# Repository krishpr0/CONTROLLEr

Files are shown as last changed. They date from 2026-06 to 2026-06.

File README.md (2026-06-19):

# CONTROLLER

CONTROLLER, IT is an Circuit which allows any type of SSD/HDD of a laptop size which is 2.5 inch Memory be a External Storage. This Project main chip is the ASM2464PD due to its high speed transfer speed. This chip was selected due to its support of USB4/Thunderbolt.

ZINE

## What is this Project?
Controller is a high speed transfer external circuit board which is meant to make any 2.5 inch hard drive or ssd into an external Storage system. This unlocks the ability to make our own external storage system rather then buying it from outside. 

## How do we use Controller?
- First of all there are 4 screws on the side 2 on each unscrew it!
- Then pull of the top cover off the base plate.
- Then insert and slide in the HDD/SSD onto the PCIe connector.
- Place the cover plate back on and then tighten the screw 2 on each side this should secure the storage as well as the top case.
- Then connect to the computer that's it!
- (*NOTE: SOME MAY REQUIRE TO FLASH A FIRMWARE*)

## The reason for building this
Nowadays the software programs are increasing in size and as the phoots, videos we click also getting bigger and bigger. In my case each of my photos clicked is more than 5MB so that storage would rlly quickly fill up and I had to either delete it or buy an external drive and store it there.!

And so I choose the 2nd opt buy and external drive to store it cuz why delete photos which is memoory.!
So yeh like that it went on for years and years pile of drives js filled with photos, videos and files but now the storage are getting more expensier and also the casing used to hold the drive. !

SO i was really frustraied atp And i thought abt is there a way to make a good external drive !?
SO that was the reason i started this project due to the rise in price of storage due to AI>
T-T

## CAD
CASE
!@45
!)(@

## CIRCUIT DIAGRAM: 










## PCB


## PCB 3D


# BOM
| #  | Reference | Value | Footprint | Qty | Unit (USD) | Total (USD) | Datasheet / Link |
|----|---|---|---|-----|---|---|---|
| 1  | U1 | ASM2464PD  USB4 Host Controller | ASM2464PD | 1 | $8.000 | $8.000 | https://www.asmedia.com.tw/product/aGaq3YfSP5Yrq0T0/cGaq7XeSw9YRQ5T1 |
| 2  | U2 | SPI Flash  SOIC-8  (Firmware storage) | SOIC-8_5.3x5.3mm_P1.27mm | 1 | $3 | $3 | http://ww1.microchip.com/downloads/en/DeviceDoc/21832H.pdf |
| 3  | U3 | SPI Flash  DFN-8  (Firmware storage) | DFN-8-1EP_3x2mm_P0.5mm | 1 | $3 | $3 | http://ww1.microchip.com/downloads/en/DeviceDoc/21832H.pdf |
| 4  | Y1 | 25MHz Crystal  SMD 3225-4Pin | Crystal_SMD_3225-4Pin_3.2x2.5mm | 1 | $0.350 | $0.350 | https://au.rs-online.com/web/p/crystal-units/9047531 |
| 5  | J1 | USB-C Receptacle  Amphenol 12401610E4-2A | USB_C_Receptacle_Amphenol | 1 | $1.200 | $1.200 | https://www.usb.org/sites/default/files/documents/usb_type-c.zip |
| 6  | J2 | SPI Header  2x04  2.54mm | PinHeader_2x04 | 1 | $0.100 | $0.100 | --- |
| 7  | J3 | PCIe x4 Connector  THT Open | PCIe_x4_tht_open | 1 | $1.500 | $1.500 | http://www.ritrontek.com/uploadfile/2016/1026/20161026105231124.pdf |
| 8  | J4 | Chip Annoyers Header  2x02  2.54mm | PinHeader_2x02 | 2 | $0.10 | $0.10 | https://www.digikey.com/en/products/detail/harwin-inc/M20-9990246/3728226 |
| 9  | J5 | UART Header  1x04  2.54mm | PinHeader_1x04 | 1 | $0.10 | $0.050 | https://www.digikey.com/en/products/detail/jst-sales-america-inc/B4B-XH-A/1651047 |
| 10 | J6 | I2C Header  1x04  2.54mm | PinHeader_1x04 | 1 | $0.10 | $0.050 | https://www.digikey.com/en/products/detail/jst-sales-america-inc/B4B-XH-A/1651047 |
| 11 | J7,J8,J9,J10 | 1x06 Header  1.27mm  x4 | PinHeader_1x06 | 4 | $0.20 | $0.200 | https://www.digikey.in/en/products/detail/jst-sales-america-inc/B6B-PH-K-S/926615 |
| 12 | R1,R2,R20,R24,R26,R29,R39,R41,R42,R43 | 1k ohm  0402 | R_0402_1005Metric | 10  | $0.15 | $1.50 | https://www.digikey.com.au/en/products/detail/yageo/RC0402FR-071KL/726513 |
| 13 | R3,R4,R5,R6,R7,R8,R25,R30,R31 | 0 ohm  0402 | R_0402_1005Metric | 9 | $0.15 | $1.35 | https://www.digikey.com.au/en/products/detail/yageo/RC0402JR-070RL/726406 |
| 14 | R9,R27,R28,R35,R38,R34,R36,R37 | 4.7k ohm  0402 | R_0402_1005Metric | 8 | $0.15 | $0.75 | https://www.digikey.com.au/en/products/detail/yageo/RC0402JR-074K7L/726477 |
| 15 | R10,R21,R22, R23 | 10k ohm  0402 | R_0201_0603Metric | 4 | $0.15 | $0.60 | https://www.digikey.com.au/en/products/detail/vishay-dale/CRCW040210K0FKED/1178121 |
| 16 | R11,R12,R13,R14,R15,R16,R17,R18 | 220k ohm  0201 | R_0201_0603Metric | 8 | $0.15 | $1.20 | https://www.digikey.com/en/products/detail/yageo/RC0201JR-07220KP/15219948 |
| 19 | R32 | 12.1k ohm  0402 | R_0402_1005Metric | 1 | $0.10 | $0.10 | https://www.digikey.in/en/products/detail/yageo/RC0402FR-1012K1L/17020868 |
| 20 | R33 | 100k ohm  0402 | R_0402_1005Metric | 1 | $0.20 | $0.20 | https://www.digikey.com/en/products/detail/yageo/AT0402BRD07100KL/5138605 |
| 22 | C1 | 10pF  0402 | C_0402_1005Metric | 1 | $0.10 | $0.10 | https://www.digikey.com/en/products/detail/yageo/CC0402JRNPO8BN100/5883266 |
| 23 | C2,C3,C4,C5,C6,C7,C8,C9 | 330nF  0201 | C_0201_0603Metric | 8 | $0.10 | $0.80 | https://www.mouser.in/ProductDetail/Walsin/0201X334M6R3CT?qs=iLbezkQI%252Bsj6TtN1Mk8apQ%3D%3D |
| 24 | C10,C21 | 1uF  0402 | C_0402_1005Metric | 2 | $0.01 | $0.02 | https://robu.in/product/1uf-capacitor-smdc-0402-pack-of-50/ |
| 25 | C11 | 220pF  0402  DNP | C_0402_1005Metric | 1 | $0.10 | $0.10 | https://www.digikey.com/en/products/detail/yageo/CC0402GRNPO9BN221/5883253 |
| 26 | C12,C13,C14,C15,C16,C17,C18,C19 | 220nF  0402 | C_0402_1005Metric | 8 | $0.003 | $0.024 | https://www.lcsc.com/product-detail/C2649521.html |
| 27 | C20 | 100nF  0402 | C_0402_1005Metric | 1 | $0.003 | $0.003 | https://www.lcsc.com/product-detail/C60474.html |
| 28 | D1,D2,D3,D4,D5,D6,D7,D8 | Diode  0201  DNP | D_0201_0603Metric | 8 | $0.32 | $2.56 | https://www.digikey.in/en/products/detail/kyocera-avx/GG020105100N2P/6826542 |
| 29 | D9,D10,D11,D12,D13,D14,D15,D16 | LED  0603 | LED_0603_1608Metric | 8 | $0.01 | $0.08 | https://www.lcsc.com/product-detail/C19171390.html |
| | TOTAL | | | | | 15.462 | |

# HOW TO BUILD










## What you need
-  Soldering Iron
-  Soldering wire
-  Flux
-  Multimeter
-  USB-C Cable

### Assembly Order
1. Solder all SMD Passives first (Resistors, Capacitors)
2. Solder ICs
3. Solder USB-C
4. Connect the PCIe Connecotr
5. Connect the Drive
6. Plug and Transfer.

### Firmware Setup 
- Open the 'firmware/src' - Upload the whole program to the SPI
- RUN

# Feature
- 1MB ROM
- SPI
- 40 GBPS USB Transfer Speed
- USB4/Thuerbolt Support
- HHD/SSD/NVMe support
- USB-C
- Power effiecent

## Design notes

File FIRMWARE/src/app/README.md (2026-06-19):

# ASM2464PD Application Tools

Tools for interacting with the ASM2464PD USB-to-PCIe bridge chip.

## probe_dma.py

Tests GPU DMA access to the ASM2464's internal SRAM buffer.

### Usage

```bash
# Basic DMA test - write via USB, read via GPU SDMA
sudo PYTHONPATH=~/tinygrad AMD_IFACE=USB python app/probe_dma.py

# Probe accessible region size
sudo PYTHONPATH=~/tinygrad AMD_IFACE=USB python app/probe_dma.py --probe-size
```

### What it tests

1. Writes test pattern to ASM2464 SRAM via USB (scsi_write to 0xF000)
2. Boots AMD GPU via tinygrad with USB interface
3. Uses GPU SDMA to copy data from PCIe address 0x200000 to GPU VRAM
4. Verifies the GPU read the correct data

This validates the DMA path: `USB -> ASM2464 SRAM <- GPU SDMA (PCIe 0x200000)`

## scan_pcie.py

Scans for PCIe devices connected via the ASM2464PD USB enclosure.

### Usage

```bash
# Quick scan (finds bridges but not downstream GPU functions)
sudo PYTHONPATH=~/tinygrad python app/scan_pcie.py

# Deep scan - configures all bridges to find GPU at bus 4
sudo PYTHONPATH=~/tinygrad python app/scan_pcie.py --deep

# Verbose mode with config space dumps
sudo PYTHONPATH=~/tinygrad python app/scan_pcie.py --deep --verbose

# Scan specific bus
sudo PYTHONPATH=~/tinygrad python app/scan_pcie.py --bus 4
```

### Example Output (with AMD RX 7900 XTX)

```
Bus 00: 32x ASM2461 PCIe Switch Ports
Bus 01: 1x ASM2461 downstream port  
Bus 02: AMD Navi 31 Upstream Port [1002:1478]
Bus 03: AMD Navi 31 Downstream Port [1002:1479]
Bus 04:
  04:00.0: AMD Navi 31 (RX 7900 XTX) [1002:744C] - Display Controller
  04:00.1: AMD Navi 31 HDMI Audio [1002:AB30] - Multimedia Controller
```

## Memory Architecture

The ASM2464PD has several memory regions accessible via different paths:

### 1. GPU-Accessible PCIe Regions (DMA Buffer)

These regions are accessible by the GPU via PCIe DMA (SDMA engine). The GPU's page
tables map virtual addresses to these PCIe physical addresses with `AddrSpace.SYS`.

| PCIe Address Range | Size | Purpose |
|---|---|---|
| 0x200000 - 0x27FFFF | 512 KB | Copy buffer (USB bulk DMA) |
| 0x800000 - 0x800FFF | 4 KB | Queue page 0 |
| 0x808000 - 0x808FFF | 4 KB | Queue page 1 |
| 0x820000 - 0x820FFF | 4 KB | Sys buffer (tinygrad) |
| 0x828000 - 0x828FFF | 4 KB | Queue page 3 |

**Total GPU-accessible**: 528 KB (512 KB contiguous + 4x4 KB pages)

The GPU can read/write these regions via SDMA. tinygrad maps them as:
- `copy_bufs[0]`: 512KB at PCIe 0x200000 (ctrl_addr 0xF000)
- `sys_buf`: 4KB at PCIe 0x820000 (ctrl_addr 0xA000)

### 2. USB-Accessible XDATA Windows

The 8051 firmware exposes these regions to USB via E4/E5 vendor commands:
- `0x8000-0x8FFF`: 4KB window (USB descriptor buffer)
- `0xF000-0xFFFF`: 4KB window (maps to PCIe 0x200000, first 4KB only)

**Note**: USB E4/E5 commands can only access the first ~4KB of the copy buffer.
The full 512KB is only accessible via GPU SDMA or SCSI bulk write.

### 3. XDATA (E4/E5 Vendor Commands)

Firmware XDATA memory accessible via USB vendor commands:
- **E4**: Read from XDATA address (up to 255 bytes)
- **E5**: Write to XDATA address (1 byte at a time)

```python
from tinygrad.runtime.support.usb import ASM24Controller
usb = ASM24Controller()

# Read 16 bytes from XDATA 0x8000
data = usb.read(0x8000, 16)

# Write bytes to XDATA 0xF000
usb.write(0xF000, b'\xDE\xAD\xBE\xEF')
```

### 4. SCSI Bulk DMA Path (Fast)

High-speed path for bulk data transfers to internal SRAM:

```python
# Write up to 64KB at a time via SCSI bulk transfer
usb.scsi_write(data, lba=0)  # Data lands at 0xF000 window
```

This is the fast path used by tinygrad for GPU memory transfers:
- USB3 bulk packets (1024 bytes each)
- Hardware DMA to internal SRAM
- No CPU involvement for data bytes

### 5. PCIe Memory (TLP Requests)

Direct PCIe memory read/write via TLP (Transaction Layer Packets):

```python
# Read 4 bytes from PCIe memory address
val = usb.pcie_mem_req(address, value=None, size=4)

# Write 4 bytes to PCIe memory address  
usb.pcie_mem_req(address, value=0xDEADBEEF, size=4)

# Batch writes for better performance
usb.pcie_mem_write(address, [val1, val2, val3, ...], size=4)
```

**Note**: PCIe memory requests go to EXTERNAL devices (GPU, NVMe), not internal SRAM.

## DMA Transfer Flow

### USB Host to GPU Memory

```
1. Host sends data via USB bulk transfer
2. ASM2464 firmware DMAs to internal SRAM (0x00200000+)
3. Data visible at XDATA 0xF000 window
4. Firmware can issue PCIe TLP to copy SRAM to GPU BAR

Or using tinygrad's copy_bufs mechanism:
1. scsi_write() to 0xF000 (lands in SRAM at ctrl_addr)
2. GPU reads from mapped sys_addr via PCIe
```

### GPU Memory to USB Host

```
1. GPU writes to mapped memory region
2. Firmware reads via PCIe TLP or DMA
3. Data copied to SRAM
4. USB bulk IN transfer to host
```

## Key Registers

### PCIe TLP Engine (0xB2xx)

| Register | Purpose |
|---|---|
| 0xB210 | TLP format/type (0x20=mem read, 0x60=mem write) |
| 0xB217 | Byte enables |
| 0xB218 | Address bits 0-7 |
| 0xB219 | Address bits 8-15 |
| 0xB21A | Address bits 16-23 |
| 0xB21B | Address bits 24-31 |
| 0xB21C | Address bits 32-39 (high) |
| 0xB220 | Data (read result / write value) |
| 0xB254 | Trigger (write 0x0F) |
| 0xB296 | Status (bit 1 = complete, bit 0 = error) |

### SCSI DMA Engine (0xCExx)

| Register | Purpose |
|---|---|
| 0xCE00 | DMA control (write 0x03 to start) |
| 0xCE75 | Transfer length |
| 0xCE76 | PCI address byte 0 (LSB) |
| 0xCE77 | PCI address byte 1 |
| 0xCE78 | PCI address byte 2 |
| 0xCE79 | PCI address byte 3 (MSB) |
| 0xCE89 | State machine (bit 0=ready, bit 1=success) |

## Requirements

- Python 3.10+
- tinygrad (for `ASM24Controller`)
- libusb
- Root access for USB device

```bash
# Install tinygrad
git clone https://github.com/tinygrad/tinygrad ~/tinygrad

# Run with correct path
sudo PYTHONPATH=~/tinygrad python app/scan_pcie.py
```

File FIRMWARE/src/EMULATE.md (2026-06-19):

Our goal is to get the emulation of the firmware running as an emulated USB device on the computer

- Emulator should run in its own thread. It should use the original firmware in fw.bin
- All communication with the emulator should be through MMIO
- It registers a dummy hcd SuperSpeed device, much be superspeed
- patch.py should work and have a model emulating the flash
- All descriptors are handled by logic in the firmware, NEVER HARDCODE ANY PIECE OF DESCRIPTORS
- All functions are handled by logic in the firmware
- The firmware runs in it's own thread and polling is done through MMIO
- There should be nothing parsing the commands in Python, the Python should just be a bridge
- The device should enumerate and show up in lsusb
- The device should show up as a mass storage device

## Current Status

### Working:
- Device enumeration (shows up in lsusb as 174c:2461)
- USB device descriptor handling via firmware DMA
- USB config descriptor with correct wTotalLength (121 bytes, includes both alt_settings)
- String descriptor handling
- Control transfers (GET_DESCRIPTOR, GET_MAX_LUN, BULK_ONLY_RESET)
- USB 2.0 High Speed mode (dummy_hcd only supports up to USB 2.0)

### Not Working:
- Bulk transfers (CBW/CSW for mass storage)
  - The bulk endpoint (0x02 OUT, 0x81 IN) is enabled but ep_read blocks
  - This may be a dummy_hcd limitation or a raw-gadget configuration issue
- UAS mode (requires USB 3.0 bulk streams, not supported by dummy_hcd)

### Known Limitations:
1. **dummy_hcd only supports USB 2.0 High Speed**
   - USB 3.0 SuperSpeed is not available
   - UAS mode requires USB 3.0 streams which are not supported
   - Device enumerates at High Speed, so USB 2.0 device descriptor is used

2. **Bulk transfers not functional**
   - The raw-gadget ep_read call blocks indefinitely waiting for data
   - Host-side libusb bulk transfers timeout with error -7
   - Control transfers work correctly, only bulk transfers are affected

## Running the Emulator

```bash
cd emulate
sudo modprobe dummy_hcd num=1
sudo modprobe raw_gadget
sudo python3 usb_device.py
```

The device will appear in lsusb:
```
Bus 005 Device XXX: ID 174c:2461 ASMedia Technology Inc. AS2462
```

## Testing

The test program `test_patch_usb.py` validates:
1. Device enumeration - PASS
2. Mass storage (BBB protocol) - FAIL (bulk transfers)
3. Vendor commands (E4/E5) - FAIL (requires bulk transfers)
4. String descriptors - PASS

Run with:
```bash
echo -n "5-1:1.0" | sudo tee /sys/bus/usb/drivers/usb-storage/unbind
sudo PYTHONPATH=/home/tiny/tinygrad python3 test_patch_usb.py
```

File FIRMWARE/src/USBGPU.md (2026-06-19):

# ASM2464PD as USBGPU - How Tinygrad Uses It

## Overview

Tinygrad uses the ASM2464PD USB4-to-NVMe bridge as a "USB GPU" by exploiting its PCIe
initiator capability and large internal SRAM buffer. This document explains the actual
implementation and identifies the slow path that needs improvement.

## Hardware Architecture

```
USB Host (tinygrad)           ASM2464PD Bridge                   GPU
       │                            │                              │
       │  USB3 Bulk Streams         │  PCIe TLPs                   │
       │  (31 concurrent)           │                              │
       │                            │                              │
       ├──EP 0x02 OUT (data)───────>│                              │
       ├──EP 0x04 OUT (commands)───>│  8051 CPU                    │
       │                            │     │                        │
       │<──EP 0x81 IN (data)────────│     ├──Config Space──────────>│
       │<──EP 0x83 IN (status)──────│     ├──Memory Write──────────>│
       │                            │     └──Memory Read───────────>│
       │                            │            │                  │
       │                            │            v                  │
       │                      Internal SRAM (6-8 MB)               │
       │                      ┌────────────────────┐               │
       │                      │ Data @ 0x00200000  │<──GPU DMA────>│
       │                      │ Queues @ 0x00820000│               │
       │                      └────────────────────┘               │
```

## Tinygrad's USB Communication

### Endpoints Used

| Endpoint | Direction | Purpose |
|---|---|---|
| 0x02 | OUT | Bulk data to device (SCSI writes) |
| 0x04 | OUT | SCSI command blocks |
| 0x81 | IN | Bulk data from device |
| 0x83 | IN | SCSI status responses |

### Buffer Allocations (from usb.py)

```python
# Per-stream buffers (31 streams for USB3 bulk streaming)
buf_data_out = 512 KB per stream    # Host → Device data
buf_data_in  = 4 KB per stream      # Device → Host data (NOTE: small!)
buf_cmd      = 32 bytes             # SCSI CDB wrapper
buf_stat     = 64 bytes             # Status response
```

### Transfer Methods

**1. SCSI WRITE (Fast - 64KB chunks)**
```python
# ScsiWriteOp in usb.py line 147-149
struct.pack('>BBQIBB', 0x8A, 0, op.lba, sectors, 0, 0)
# 0x8A = SCSI WRITE(16) opcode
# lba = Logical Block Address (maps to PCI address 0x00200000 + lba*512)
# sectors = size / 512

# Chunking (usb.py lines 156-160)
for i in range(0, len(buf), 0x10000):  # 64 KB chunks
    self.exec_ops([ScsiWriteOp(buf[i:i+0x10000], lba), ...])
```

**2. E4 Read (SLOW - 255 byte chunks)**
```python
# ReadOp in usb.py line 143-146
struct.pack('>BBBHB', 0xE4, op.size, addr >> 16, addr & 0xFFFF, 0)
# op.size limited to 0xFF (255 bytes)

# Read method (usb.py line 165-167)
def read(self, base_addr, length, stride=0xff):  # stride = 255!
    parts = self.exec_ops([ReadOp(base_addr + off, min(stride, length - off))
                           for off in range(0, length, stride)])
```

**3. E5 Write (Register access - 1 byte at a time)**
```python
# WriteOp in usb.py line 136-141
struct.pack('>BBBHB', 0xE5, value, addr >> 16, addr & 0xFFFF, 0)
# Single byte per command - used for MMIO register writes, not bulk data
```

### Speed Comparison

| Operation | Chunk Size | Throughput | Use Case |
|---|---|---|---|
| SCSI WRITE (0x8A) | 64 KB | ~100+ MB/s | Fast bulk OUT |
| E4 Read (0xE4) | 255 bytes | ~1-5 MB/s | **SLOW** bulk IN |
| E5 Write (0xE5) | 1 byte | ~10-50 KB/s | Register config |
| PCIe MemWr | 4 bytes | ~4 MB/s | GPU BAR writes |
| PCIe MemRd | 4 bytes | ~2 MB/s | GPU BAR reads |

**The asymmetry is severe**: Writes are ~20-100x faster than reads.

## The Firmware Patch

Tinygrad's `patch.py` downloads ASMedia firmware and makes one modification:

```python
patches = [(0x2a0d + 1 + 4, b'\x0a', b'\x05')]
# File offset: 0x2a12
# Changes: mov r7, #0x0a → mov r7, #0x05
```

### What The Patch Does

At code address 0x2a0d, there's a SCSI write completion status check:

```c
// From src/app/protocol.c lines 2250-2267
if (*ptr != 0) {
    goto return_0x0a;  // Return error code 10
}
// ...
return_0x0a:
    // NOTE: patch.py changes this return value from 0x0a to 0x05
    return 0x0a;  // Original returns 10
```

The patch changes this return value from 0x0a (10) to 0x05 (5).

**Why?** The return value is a status code that affects the SCSI state machine.
Code 10 (0x0a) indicates one type of completion status, while code 5 (0x05)
indicates another. The patch likely changes how partial/retry scenarios are
handled to make the write path more reliable for tinygrad's usage pattern.

### VID/PID Change

The patch also changes the device identity via config blocks:

```
Original:  VID=0x174C PID=0x2464 (ASMedia USB4 NVMe)
Patched:   VID=0xADD1 PID=0x0001 ("tiny")
```

This allows tinygrad to identify its patched devices.

## Internal SRAM Buffer

### Size: 6-8 MB

```
PCI Address       Purpose
0x00200000        Data buffer start (6+ MB available)
0x00820000        NVMe queues (can be repurposed)

Gap = 0x00620000 = 6.125 MB for data buffer
```

### LBA Addressing

SCSI commands use LBA (Logical Block Address) which firmware converts:

```
buffer_addr = 0x00200000 + (LBA × 512)
```

So `ScsiWriteOp(data, lba=256)` writes to PCI address:
```
0x00200000 + (256 × 512) = 0x00220000
```

### 32-bit DMA Addressing

The 8051 has 64KB address space but accesses the full buffer via DMA registers:

```
Register   Purpose
CE76-CE79  32-bit DMA address (little-endian)
```

USB bulk transfers program these registers and let hardware DMA handle the data.
The 8051 CPU never touches the bulk data bytes.

## The Slow Path Problem

### Why E4 Reads Are Slow

E4 is a vendor-specific SCSI command for register/memory reads:

1. **Limited to 255 bytes per request** (line 143: `assert op.size <= 0xff`)
2. **Control transfer overhead** - each E4 goes through SCSI CDB processing
3. **No bulk streaming** - cannot pipeline like SCSI WRITE does

### Why SCSI READ Isn't Used

Standard SCSI READ(16) command (opcode 0x88) isn't implemented in tinygrad.
The firmware supports it, but tinygrad only implemented SCSI WRITE.

### Comparison: SCSI WRITE vs E4 READ

```
SCSI WRITE (current - fast):
  1 command → 64KB data → 1 status
  ~100 MB/s

E4 READ (current - slow):
  1 command → 255 bytes data → 1 status
  × 4000 times for 1 MB
  ~1-5 MB/s
```

## Plan to Fix the Slow Path

### Option 1: Implement ScsiReadOp (Recommended)

Add SCSI READ(16) support to tinygrad, mirroring the write path:

```python
@dataclasses.dataclass(frozen=True)
class ScsiReadOp: size:int; lba:int=0

# In exec_ops:
elif isinstance(op, ScsiReadOp):
    sectors = round_up(op.size, 512) // 512
    _add_req(struct.pack('>BBQIBB', 0x88, 0, op.lba, sectors, 0, 0),
             sectors * 512, None)  # Request data IN

def scsi_read(self, size:int, lba:int=0) -> bytes:
    # Chunk reads like writes
    result = b''
    for i in range(0, size, 0x10000):
        chunk_size = min(0x10000, size - i)
        resp = self.exec_ops([ScsiReadOp(chunk_size, lba + i // 512)])
        result += resp[0][:chunk_size]
    return result
```

**Expected improvement:** 255 bytes → 64 KB per request = **~250x faster**

### Option 2: Batch E4 Requests

If firmware changes are easier than tinygrad changes:

```python
# Current: Sequential 255-byte reads
for off in range(0, length, 255):
    result += exec_ops([ReadOp(addr + off, 255)])

# Better: Parallel 255-byte reads (use all 31 streams)
reads = [ReadOp(addr + off, 255) for off in range(0, length, 255)]
results = exec_ops(reads[:31])  # 31 concurrent = 7.9KB per batch
```

**Expected improvement:** ~31x faster (still limited by E4 overhead)

### Option 3: Larger E4 Transfers (Firmware Change)

The 255-byte limit is arbitrary. Firmware could support larger E4 reads:

```c
// Current: uint8_t limits to 255
// Change: Use 16-bit length field in E4 command

// E4 format: 0xE4 [size_hi] [addr>>16] [addr_lo] [addr_hi] [size_lo]
// Allows up to 64KB per E4 request
```

**Expected improvement:** ~250x faster with firmware mod

### Option 4: Use GPU Bus Mastering

For large reads from GPU memory, use the GPU as bus master:

1. GPU DMAs data to PCI address 0x00200000 (bridge's SRAM)
2. Tinygrad reads from SRAM via SCSI READ or E4
3. Eliminates slow PCIe MemRd TLPs from 8051

**Expected improvement:** GPU-limited rather than bridge-limited

## Summary

| Path | Current | After Fix | Improvement |
|---|---|---|---|
| USB → Device (SCSI WRITE) | 64 KB/cmd | 64 KB/cmd | Already fast |
| Device → USB (E4 READ) | 255 B/cmd | 64 KB/cmd | **~250x** |
| 8051 → GPU (PCIe MemWr) | 4 B/TLP | 4 B/TLP | Can't improve* |
| GPU → 8051 (PCIe MemRd) | 4 B/TLP | 4 B/TLP | Can't improve* |
| GPU ↔ SRAM (bus master) | N/A | ~4 GB/s | Use this! |

*The 8051-initiated PCIe path is fundamentally slow (~4 MB/s max). Use GPU
bus mastering for high-throughput data movement.

## Quick Reference

### Tinygrad Device Opening

```python
# From usb.py line 117
self.usb = USB3(0xADD1, 0x0001, 0x81, 0x83, 0x02, 0x04)
#              VID     PID     data_in stat_in data_out cmd_out
```

### Controller Initialization

```python
# usb.py lines 123-124
self.exec_ops([
    WriteOp(0x54b, b' '),        # Unknown config
    WriteOp(0x54e, b'\x04'),     # Unknown config
    WriteOp(0x5a8, b'\x02'),     # Unknown config
    WriteOp(0x5f8, b'\x04'),     # Unknown config
    WriteOp(0x7ec, b'\x01\x00\x00\x00'),  # 4-byte config
    WriteOp(0xc422, b'\x02'),    # Enable something
    WriteOp(0x0, b'\x33'),       # Start signal?
])
```

### PCIe Memory Access

```python
# usb.py lines 185-214
def pcie_request(self, fmt_type, address, value=None, size=4):
    # fmt_type: 0x60=MemWr, 0x20=MemRd
    # Writes to B210-B296 registers to generate TLPs

def pcie_mem_write(self, address, values, size):
    # Batch PCIe memory writes (4 on OSX, 16 on Linux per batch)
```

---

# Hardware Blocks for USBGPU Firmware

This section details all hardware blocks in the ASM2464PD and their relevance for
a USBGPU-specific firmware rewrite.

## Block Diagram

```
                              ASM2464PD SoC
    ┌──────────────────────────────────────────────────────────────────┐
    │                                                                  │
    │  ┌──────────┐    ┌──────────────────────────────────────────┐   │
    │  │  8051    │    │           Internal SRAM (6-8 MB)          │   │
    │  │   CPU    │    │  ┌────────────────────────────────────┐  │   │
    │  │ ~100MHz  │    │  │ 0x00200000: Data Buffer (6 MB)     │  │   │
    │  │          │    │  │ 0x00820000: Queue Region (128 KB)  │  │   │
    │  │ 64KB     │    │  └────────────────────────────────────┘  │   │
    │  │ XDATA    │    │                    ▲                     │   │
    │  │ views    │    │                    │ 32-bit DMA          │   │
    │  └────┬─────┘    └────────────────────┼─────────────────────┘   │
    │       │                               │                         │
    │       ▼                               ▼                         │
    │  ┌─────────────────────────────────────────────────────────┐   │
    │  │                    DMA Engines                          │   │
    │  │  ┌─────────┐  ┌─────────┐  ┌─────────┐  ┌─────────┐    │   │
    │  │  │USB DMA  │  │SCSI DMA │  │XFER DMA │  │Flash DMA│    │   │
    │  │  │0x90xx   │  │0xCExx   │  │0xCCxx   │  │0xC8Ax   │    │   │
    │  │  └────┬────┘  └────┬────┘  └────┬────┘  └────┬────┘    │   │
    │  └───────┼────────────┼────────────┼────────────┼──────────┘   │
    │          │            │            │            │               │
    │          ▼            ▼            ▼            ▼               │
    │  ┌─────────────┐ ┌─────────────┐ ┌──────┐ ┌──────────────┐     │
    │  │USB3 Ctrl   │ │PCIe Engine  │ │Timers│ │SPI Flash     │     │
    │  │0x9000-93FF │ │0xB200-B4FF  │ │0xCC10│ │0xC89F-C8AE   │     │
    │  │            │ │             │ │      │ │              │     │
    │  │EP0 Control │ │TLP Generate │ │Timer0│ │Config Store  │     │
    │  │EP1 Bulk IN │ │Config Space │ │Timer1│ │              │     │
    │  │EP2 Bulk OUT│ │Memory R/W   │ │Timer2│ │              │     │
    │  └──────┬─────┘ └──────┬──────┘ │Timer3│ └──────────────┘     │
    │         │              │        └──────┘                       │
    └─────────┼──────────────┼───────────────────────────────────────┘
              │              │
              ▼              ▼
         USB3 PHY       PCIe PHY
              │              │
              ▼              ▼
         To Host         To GPU
```

## Hardware Blocks - Detailed Analysis

### 1. USB3 Controller (0x9000-0x93FF) - **ESSENTIAL**

The USB3 controller handles all host communication. **Required for USBGPU.**

| Register Range | Purpose | USBGPU Need |
|---|---|---|
| 0x9000-0x901F | Core USB status/control | Required |
| 0x905A-0x90FF | Endpoint configuration | Required |
| 0x9091-0x9092 | Control transfer phase, DMA trigger | Required |
| 0x9100-0x912F | Link status, CDB registers | Required |
| 0x91C0-0x91FF | USB PHY control | Required |
| 0x9200-0x92FF | Power management | Required |
| 0x9E00-0x9E07 | Setup packet buffer | Required |

**Key Registers for USBGPU:**
```
0x9000  USB_STATUS      - Connection state (bit 7=connected)
0x9091  USB_CTRL_PHASE  - Control transfer state machine
0x9092  USB_DMA_TRIGGER - Triggers descriptor DMA
0x9100  USB_LINK_STATUS - USB speed (bits 0-1: 2=SuperSpeed)
0x910D-0x9112 USB_CDB   - SCSI Command Descriptor Block
0x9E00-0x9E07 Setup Pkt - 8-byte USB setup packet
```

**Simplification:** Remove Mass Storage class, use Vendor class for simpler protocol.

---

### 2. SCSI/Bulk DMA Engine (0xCE00-0xCE9F) - **ESSENTIAL**

This is the high-speed bulk transfer engine. **Critical for USBGPU performance.**

| Register Range | Purpose | USBGPU Need |
|---|---|---|
| 0xCE00-0xCE01 | DMA control/parameter | Required |
| 0xCE40-0xCE45 | DMA parameters | Required |
| 0xCE55 | Tag value | Required |
| 0xCE66-0xCE67 | Tag count, queue status | Required |
| 0xCE70-0xCE79 | Transfer control, **32-bit PCI address** | **Critical** |
| 0xCE86-0xCE89 | USB/DMA state machine | Required |

**Key Registers:**
```
0xCE00  SCSI_DMA_CTRL   - Write 0x03 to start transfer
0xCE76-CE79 BUF_ADDR    - 32-bit PCI address into SRAM (NOT XDATA!)
0xCE89  USB_DMA_STATE   - State machine (bit 0=ready, 1=success, 2=complete)
```

**This is how USB bulk transfers access the full 6-8MB SRAM without 8051 involvement.**

---

## DMA Engines - Deep Dive

This section explains exactly what each DMA engine transfers between.

### Memory Architecture

```
                    ASM2464PD Memory Architecture
                    ==============================

┌─────────────────────────────────────────────────────────────────────┐
│                        PCI Address Space                            │
│  (What downstream devices see / what DMA engines use)               │
├─────────────────────────────────────────────────────────────────────┤
│                                                                     │
│  0x00000000 ┌─────────────────────────────────────────────────┐    │
│             │              Reserved                            │    │
│  0x00200000 ├─────────────────────────────────────────────────┤    │
│             │                                                  │    │
│             │         DATA BUFFER (6+ MB)                      │    │
│             │                                                  │    │
│             │   - USB bulk data lands here                     │    │
│             │   - GPU can DMA to/from here                     │    │
│             │   - NVMe data transfers use this                 │    │
│             │                                                  │    │
│  0x00820000 ├─────────────────────────────────────────────────┤    │
│             │         COMMAND QUEUES (128 KB)                  │    │
│             │   - NVMe submission/completion queues            │    │
│             │   - Can be repurposed for GPU commands           │    │
│  0x00840000 └─────────────────────────────────────────────────┘    │
│                                                                     │
└─────────────────────────────────────────────────────────────────────┘
                              ▲
                              │ Hardware maps to
                              ▼
┌─────────────────────────────────────────────────────────────────────┐
│                     Internal SRAM (Physical)                        │
│                     ~8 MB on-chip memory                            │
└─────────────────────────────────────────────────────────────────────┘
                              ▲
                              │ 8051 sees only windows
                              ▼
┌─────────────────────────────────────────────────────────────────────┐
│                    8051 XDATA Address Space                         │
│                    (64 KB, 0x0000-0xFFFF)                           │
├─────────────────────────────────────────────────────────────────────┤
│  0x0000-0x5FFF  Working memory, globals, tables                     │
│  0x6000-0x6FFF  Reserved                                            │
│  0x7000-0x7FFF  Flash buffer (4KB window)                           │
│  0x8000-0x8FFF  USB buffer (4KB window into PCI 0x00200000+)        │
│  0x9000-0x9FFF  MMIO: USB controller                                │
│  0xA000-0xAFFF  NVMe IOSQ (4KB window into PCI 0x00820000+)         │
│  0xB000-0xBFFF  NVMe ASQ/ACQ + PCIe TLP engine                      │
│  0xC000-0xEFFF  MMIO: Various controllers                           │
│  0xF000-0xFFFF  NVMe data (4KB window into PCI 0x00200000+)         │
└─────────────────────────────────────────────────────────────────────┘
```

### DMA Engine 1: USB Descriptor DMA (0x9092)

**Purpose:** Transfer USB descriptors from firmware ROM to USB hardware buffer

```
Source:      Code ROM (descriptor tables at 0x0627, 0x58CF, etc.)
Destination: USB hardware buffer (feeds directly to USB PHY)
Trigger:     Write 0x01 to 0x9092
Completion:  Check 0xE712 bits 0-1
```

**Data Flow:**
```
Firmware ROM ──DMA──> USB TX Buffer ──USB PHY──> Host
  (0x0627)           (hardware)
```

**Key Registers:**
```
0x905B-905C  Source address (16-bit ROM address)
0x9004-9005  Transfer length (16-bit)
0x9092       Trigger (write 0x01)
0xE712       Completion status
```

**Not for bulk data** - only for enumeration descriptors (<256 bytes).

---

### DMA Engine 2: SCSI/Bulk DMA (0xCE00-0xCE9F) - **THE FAST PATH**

**Purpose:** Transfer bulk data between USB and internal SRAM using PCI addresses

```
Source:      USB bulk endpoint OR internal SRAM
Destination: Internal SRAM OR USB bulk endpoint
Addressing:  32-bit PCI address space (0x00200000+)
Trigger:     Write 0x03 to 0xCE00
Completion:  Poll 0xCE89 or 0xCE00
```

**This is the high-speed path that enables USB3 throughput.**

**Data Flow (USB OUT - Host to Device):**
```
Host ──USB3 Bulk──> USB HW ──SCSI DMA──> SRAM[PCI addr]
                                          (0x00200000+)
```

**Data Flow (USB IN - Device to Host):**
```
SRAM[PCI addr] ──SCSI DMA──> USB HW ──USB3 Bulk──> Host
 (0x00200000+)
```

**Key Registers:**
```
0xCE76  BUF_ADDR0  - PCI address byte 0 (LSB)
0xCE77  BUF_ADDR1  - PCI address byte 1
0xCE78  BUF_ADDR2  - PCI address byte 2
0xCE79  BUF_ADDR3  - PCI address byte 3 (MSB)
0xCE75  BUF_LEN    - Transfer length
0xCE00  DMA_CTRL   - Write 0x03 to start, poll for 0x00
0xCE89  DMA_STATE  - State machine (bits: ready, success, complete)
```

**Address Calculation:**
```c
// Firmware calculates PCI address from SCSI LBA:
pci_addr = 0x00200000 + (lba * 512);

// Then writes to CE76-CE79:
REG_SCSI_BUF_ADDR0 = (pci_addr >> 0) & 0xFF;
REG_SCSI_BUF_ADDR1 = (pci_addr >> 8) & 0xFF;
REG_SCSI_BUF_ADDR2 = (pci_addr >> 16) & 0xFF;
REG_SCSI_BUF_ADDR3 = (pci_addr >> 24) & 0xFF;
```

**The 8051 CPU never touches bulk data bytes** - it only configures addresses.

---

### DMA Engine 3: PCIe/Vendor DMA (0xB296)

**Purpose:** Transfer data between XDATA and USB buffer for E4/E5 vendor commands

```
Source:      XDATA (any address 0x0000-0xFFFF)
Destination: USB buffer at 0x8000
Trigger:     Write 0x08 to 0xB296
Completion:  Check 0xB296 bits 1-2
```

**Data Flow (E4 Read):**
```
XDATA[addr] ──DMA──> USB buffer (0x8000) ──USB──> Host
                         (4KB)
```

**Key Registers:**
```
0x910F  ADDR_HI   - Source address high byte
0x9110  ADDR_MID  - Source address mid byte
0x9111  ADDR_LO   - Source address low byte
0x910E  SIZE      - Transfer size (max 255 bytes)
0xB296  TRIGGER   - Write 0x08 to start
0xB296  STATUS    - Bit 1=complete, Bit 0=error
```

**Limited to XDATA window** - cannot access full PCI address space.
**Slow** - only 255 bytes per transfer.

---

### DMA Engine 4: Flash DMA (0xC8A9)

**Purpose:** Transfer between SPI flash and XDATA buffer

```
Source:      SPI flash (external chip)
Destination: Flash buffer at 0x7000-0x7FFF
Trigger:     Write 0x01 to 0xC8A9
Completion:  Poll 0xC8A9 bit 0 until clear
```

**Data Flow:**
```
SPI Flash ──DMA──> XDATA[0x7000-0x7FFF]
                       (4KB buffer)
```

**Not relevant for USBGPU runtime** - only used for config/firmware loading.

---

### DMA Engine 5: Internal Transfer DMA (0xC8B8, 0xCC89)

**Purpose:** Block transfers within XDATA memory

```
Source:      XDATA address
Destination: XDATA address
Trigger:     Write 0x01 to 0xC8B8
Completion:  Poll 0xC8D6 bit 2
```

**Key Registers:**
```
0xC8B0  DMA_MODE      - Mode configuration
0xC8B4-B5 XFER_CNT    - Transfer count (16-bit)
0xC8B6  CHAN_CTRL     - Direction, enable
0xC8B8  TRIGGER       - Write 0x01 to start
0xC8D6  STATUS        - Bit 2=done, Bit 3=error
```

**Used for:** Internal memory copies, register block operations.

---

### Summary: DMA Source/Destination Matrix

| DMA Engine | Source | Destination | Addressing | Max Size |
|---|---|---|---|---|
| USB Descriptor | ROM | USB HW | 16-bit ROM | ~256 B |
| **SCSI/Bulk** | **USB/SRAM** | **SRAM/USB** | **32-bit PCI** | **~8 MB** |
| PCIe/Vendor | XDATA | USB buf | 24-bit XDATA | 255 B |
| Flash | SPI chip | XDATA | 24-bit flash | 4 KB |
| Internal | XDATA | XDATA | 16-bit XDATA | 64 KB |

### Critical Insight for USBGPU

**The SCSI/Bulk DMA (CE76-CE79) is the ONLY path for high-speed transfers.**

- It uses **32-bit PCI addresses** (0x00200000+), NOT 8051 XDATA addresses
- The 8051's 0x8000 and 0xF000 windows are just **4KB views** into this larger space
- The hardware DMA moves data directly between USB and SRAM at **GB/s speeds**
- The 8051 CPU only writes addresses and triggers - **never touches data bytes**

```
USB3 Host                           Internal SRAM
    │                                    │
    │  USB bulk packets                  │
    │  (1024 bytes each)                 │
    ▼                                    ▼
┌───────────┐                     ┌──────────────┐
│ USB       │   Hardware DMA      │  0x00200000  │
│ Controller│ ════════════════════│  Data Buffer │
│           │   (CE76-79 addr)    │  (6-8 MB)    │
└───────────┘                     └──────────────┘
                                        ▲
                                        │ 4KB window
                                        ▼
                                  ┌──────────────┐
                                  │ 8051 XDATA   │
                                  │ 0x8000-0x8FFF│
                                  │ (CPU access) │
                                  └──────────────┘
```

---

### 3. PCIe TLP Engine (0xB200-0xB4FF) - **ESSENTIAL**

Generates PCIe transactions to the GPU. **Required for GPU communication.**

| Register Range | Purpose | USBGPU Need |
|---|---|---|
| 0xB210-0xB220 | TLP format, address, data | Required |
| 0xB22A-0xB22D | Completion status/data | Required |
| 0xB234-0xB24E | Extended link state | Optional |
| 0xB250-0xB254 | Doorbell, trigger | Required |
| 0xB296 | PCIe status | Required |
| 0xB401-0xB482 | Tunnel control | USB4 only |

**Key Registers:**
```
0xB210  PCIE_FMT_TYPE   - TLP type (0x00=MemRd, 0x40=MemWr)
0xB213  PCIE_TLP_CTRL   - Enable TLP (write 0x01)
0xB217  PCIE_BYTE_EN    - Byte enables (0x0F = all 4)
0xB218-B21B PCIE_ADDR   - 32-bit GPU address
0xB220  PCIE_DATA       - 4-byte write data
0xB22C  PCIE_CPL_DATA   - 4-byte read completion data
0xB254  PCIE_TRIGGER    - Send TLP (write 0x0F)
0xB296  PCIE_STATUS     - Bit 1=complete, 0=error
```

**Limitation:** Only 4 bytes per TLP. No hardware DMA to GPU - all CPU-initiated.

---

### 4. Internal DMA/Transfer Engine (0xC8B0-0xCCFF) - **ESSENTIAL**

Internal memory block transfers and CPU DMA control.

| Register Range | Purpose | USBGPU Need |
|---|---|---|
| 0xC8B0-0xC8D9 | DMA engine core | Required |
| 0xCC80-0xCC9B | CPU DMA control | Required |
| 0xCCD8-0xCCDB | Secondary transfer DMA | Optional |

**Key Registers:**
```
0xC8B8  DMA_TRIGGER     - Start internal DMA
0xC8D6  DMA_STATUS      - Bit 2=done, bit 3=error
0xCC89  XFER_DMA_CMD    - Transfer DMA command/status
```

---

### 5. Timer System (0xCC10-0xCC24) - **REQUIRED**

Hardware timers for delays and timeouts.

| Timer | Address | Purpose | USBGPU Need |
|---|---|---|---|
| Timer0 | 0xCC10-0xCC13 | System tick, ISR | Required |
| Timer1 | 0xCC16-0xCC19 | Protocol timeout | Required |
| Timer2 | 0xCC1C-0xCC1F | USB timing | Required |
| Timer3 | 0xCC22-0xCC24 | Idle timeout | Optional |

**Key Registers:**
```
0xCC11  TIMER0_CSR      - Bit 0=enable, 1=expired, 2=clear
0xCC12-13 THRESHOLD     - 16-bit count value
```

---

### 6. Interrupt Controller (0xC800-0xC80F) - **REQUIRED**

Manages hardware interrupts to 8051.

| Register | Purpose | USBGPU Need |
|---|---|---|
| 0xC800 | Interrupt status | Required |
| 0xC801 | Interrupt enable | Required |
| 0xC802 | USB interrupt status | Required |
| 0xC806 | System interrupt status | Required |
| 0xC80A | PCIe/NVMe interrupt status | Required |

---

### 7. USB Endpoint Buffer (0xD800-0xDFFF) - **REQUIRED**

Hardware buffer for USB endpoint data.

| Register | Purpose | USBGPU Need |
|---|---|---|
| 0xD800-0xD80F | EP control/CSW | Required |
| 0xD803-0xD804 | Buffer pointer (16-bit) | Required |
| 0xDE30-0xDE36 | Extended EP config | Optional |

---

### 8. SPI Flash Controller (0xC89F-0xC8AE) - **MINIMAL**

For firmware/config storage. Minimal use in USBGPU.

| Register | Purpose | USBGPU Need |
|---|---|---|
| 0xC8A9 | Flash CSR (bit 0=busy) | Config read only |
| 0xC8AA | Flash command | Config read only |

**Simplification:** Read-only config at boot, no runtime flash access needed.

---

### 9. NVMe Controller (0xC400-0xC5FF) - **NOT NEEDED**

NVMe command processing and queue management.

| Register Range | Purpose | USBGPU Need |
|---|---|---|
| 0xC400-0xC44F | NVMe command engine | Not needed |
| 0xC450-0xC52F | Queue management | Not needed |
| 0xC4C0-0xC4CA | SCSI-NVMe translation | Not needed |
| 0xC4ED-0xC4EF | NVMe DMA control | Not needed |

**Remove entirely** - USBGPU doesn't need NVMe protocol.

---

### 10. NVMe Queue Buffers (0xA000-0xB1FF) - **REPURPOSE**

XDATA regions for NVMe queues. **Can be repurposed for USBGPU.**

| Region | Original Use | USBGPU Use |
|---|---|---|
| 0xA000-0xAFFF (4KB) | NVMe I/O Submission Queue | GPU command queue |
| 0xB000-0xB0FF (256B) | NVMe Admin Submission Queue | General use |
| 0xB100-0xB1FF (256B) | NVMe Admin Completion Queue | GPU completion |

---

### 11. UART (0xC000-0xC00F) - **OPTIONAL**

Debug output. Keep for development, remove for production.

---

### 12. I2C Controller (0xC870-0xC87F) - **NOT NEEDED**

For external EEPROM/sensors. Not used in USBGPU.

---

### 13. PHY Controllers (0xC200-0xC6FF) - **MINIMAL**

USB and PCIe PHY configuration. Mostly init-time only.

| Block | Address | USBGPU Need |
|---|---|---|
| Link/PHY Control | 0xC200-0xC2FF | Init only |
| PHY Extended | 0xC600-0xC6FF | Init only |
| PHY Completion | 0xE300-0xE3FF | Debug only |

---

## USBGPU Firmware Architecture

### Minimal Required Blocks

```
┌────────────────────────────────────────────────────────────────┐
│                     USBGPU Firmware                            │
├────────────────────────────────────────────────────────────────┤
│                                                                │
│  ┌─────────────┐   ┌─────────────┐   ┌─────────────┐          │
│  │USB Handler  │   │DMA Engine   │   │PCIe Engine  │          │
│  │             │   │             │   │             │          │
│  │- Vendor Cmd │   │- Bulk IN    │   │- MemWr TLP  │          │
│  │- Bulk EP    │   │- Bulk OUT   │   │- MemRd TLP  │          │
│  │- Descriptors│   │- 32-bit Addr│   │- Config Spc │          │
│  └─────────────┘   └─────────────┘   └─────────────┘          │
│        │                 │                 │                   │
│        ▼                 ▼                 ▼                   │
│  ┌──────────────────────────────────────────────────┐         │
│  │              Register Interface                   │         │
│  │  USB: 0x9000    DMA: 0xCE00    PCIe: 0xB200      │         │
│  └──────────────────────────────────────────────────┘         │
│                          │                                     │
│                          ▼                                     │
│  ┌──────────────────────────────────────────────────┐         │
│  │                 Minimal Support                   │         │
│  │  Timers: 0xCC10   Interrupts: 0xC800   Init only │         │
│  └──────────────────────────────────────────────────┘         │
│                                                                │
└────────────────────────────────────────────────────────────────┘
```

### Code Size Estimate

| Component | Current FW | USBGPU FW | Notes |
|---|---|---|---|
| USB Core | ~8 KB | ~4 KB | Remove MSC class |
| SCSI Layer | ~12 KB | 0 KB | Remove entirely |
| NVMe Layer | ~16 KB | 0 KB | Remove entirely |
| DMA Engine | ~4 KB | ~2 KB | Keep bulk path |
| PCIe TLP | ~6 KB | ~3 KB | Keep MemR/W |
| Init/Config | ~4 KB | ~2 KB | Simplify |
| **Total** | ~50 KB | **~11 KB** | **~78% reduction** |

### Register Summary for USBGPU

**Must Have (Essential):**
```
0x9000-0x93FF  USB Controller
0xB210-0xB296  PCIe TLP Engine
0xCE00-0xCE9F  SCSI/Bulk DMA
0xC800-0xC80A  Interrupt Controller
0xCC10-0xCC24  Timers
0xD800-0xD80F  EP Buffer
```

**Init Only:**
```
0x92C0-0x92FF  Power Management
0xC200-0xC2FF  PHY Control
0xC89F-0xC8AE  Flash (config read)
```

**Remove/Ignore:**
```
0xC400-0xC5FF  NVMe Controller
0xA000-0xB1FF  NVMe Queues (repurpose as data)
0xC870-0xC87F  I2C
0xEC00-0xECFF  NVMe Events
```

### Simplified Data Flow

```
                    USBGPU Data Flow
                    ================

USB Bulk OUT (Host → GPU):
  Host ──USB3──> EP2 ──DMA──> SRAM[0x00200000]
                              8051 reads SRAM window
                              8051 ──TLP──> GPU BAR

USB Bulk IN (GPU → Host):
  GPU ──DMA──> SRAM[0x00200000]  (GPU as bus master)
             or
  8051 ──TLP──> GPU BAR → 8051 → SRAM  (slow path)
  SRAM ──DMA──> EP1 ──USB3──> Host

Register Access (E5 Write):
  Host ──USB3──> Setup Pkt (0x9E00)
                8051 parses → writes register

Memory Read (E4 Read):
  Host ──USB3──> CDB (0x910D)
                8051 reads XDATA → DMA → USB IN
```

### Implementation Priority

1. **Phase 1: USB Vendor Class**
   - Replace Mass Storage descriptors with Vendor class
   - Simplify enumeration (no SCSI inquiry, mode sense, etc.)
   - Keep bulk endpoints for data transfer

2. **Phase 2: Direct Bulk Protocol**
   - Define simple command format (opcode, address, length)
   - Direct DMA from bulk EP to SRAM
   - Bypass all SCSI/NVMe processing

3. **Phase 3: Fast Read Path**
   - Implement SCSI READ(16) equivalent for bulk reads
   - Or extend E4 to support 64KB reads
   - Use hardware DMA for data movement

4. **Phase 4: GPU Bus Master Integration**
   - Configure GPU as PCIe bus master
   - GPU DMAs directly to SRAM (0x00200000)
   - 8051 only handles command/status, not data

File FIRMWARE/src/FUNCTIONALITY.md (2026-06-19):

# ASM2464PD USB4 eGPU Firmware

## Overview

The ASM2464PD is a USB4/Thunderbolt to PCIe bridge. It translates USB Mass Storage (SCSI) commands into NVMe transactions, enabling external SSDs and eGPUs over Thunderbolt.

```
┌─────────────┐     ┌─────────────────────────────┐     ┌─────────────┐
│  USB Host   │────>│       ASM2464PD             │────>│  NVMe SSD   │
│  (SCSI/UAS) │<────│  8051 CPU @ 114MHz          │<────│  or eGPU    │
└─────────────┘     └─────────────────────────────┘     └─────────────┘
                      │                         │
                      │  USB 3.2 Gen2x2         │  PCIe Gen4 x4
                      │  (20 Gbps)              │  (64 Gbps)
```

## Hardware Components

| Component | Registers | Purpose |
|---|---|---|
| USB Controller | 0x9000-0x93FF | USB endpoints, CBW/CSW handling |
| PCIe Interface | 0xB200-0xB4FF | TLP transactions, config space |
| NVMe Controller | 0xC400-0xC5FF | SQ/CQ management, doorbells |
| DMA Engine | 0xC8B0-0xC8DF | Data movement USB<->PCIe |
| PHY/Link | 0xC200-0xC6FF | Signal conditioning, link training |
| Timer | 0xCC10-0xCC24 | Timeouts, delays |
| Flash | 0xC89F-0xC8AE | Firmware storage |

## Memory Map

```
XDATA Address Space:
0x0000-0x5FFF  24KB XRAM (globals, work areas)
0x6000-0x6FFF  Reserved
0x7000-0x7FFF  Flash buffer
0x8000-0x8FFF  USB/SCSI buffer (CBW parsing)
0x9000-0x9FFF  USB registers
0xA000-0xAFFF  NVMe I/O Submission Queue
0xB000-0xB1FF  NVMe Admin Queues (ASQ/ACQ)
0xB200-0xBFFF  PCIe registers
0xC000-0xCFFF  Peripheral registers
0xD800-0xDFFF  USB endpoint buffers (CSW)
0xE000-0xEFFF  Debug/status registers
0xF000-0xFFFF  NVMe data buffer
```

## Initialization Flow

```
main()
  ├─> uart_init()                    // Debug @ 921600 baud
  ├─> process_init_table()           // Hardware config from table
  ├─> usb_power_init()               // Power domains
  │     ├─ REG_POWER_ENABLE = 0x81
  │     ├─ REG_CLOCK_ENABLE = 0x03
  │     └─ REG_PHY_POWER = 0x04
  ├─> phy_init_sequence()            // PHY power up
  │     ├─ Clear USB PHY (0x920C)
  │     ├─ Enable PHY (0x92C5)
  │     └─ Poll ready (0xC6B3)
  ├─> phy_config_link_params()       // Lane config
  │     ├─ Set lanes (0xC62D = 0x07)
  │     └─ Extended PHY (0xC65B)
  └─> main_loop()                    // Service USB/PCIe/NVMe
```

## PCIe Tunnel Setup (USB4/Thunderbolt)

```
pcie_tunnel_enable (0xC00D)
  ├─> pcie_tunnel_setup (0xCD6C)
  │     └─> pcie_adapter_config (0xC8DB)
  │           ├─ Load config from 0x0A52-0x0A55
  │           └─ Write to REG_TUNNEL_* (0xB410-0xB41B)
  └─> pcie_lane_config (0xD436)
        └─> pcie_lane_config_helper (0xC089)
              ├─> phy_link_training (0xD702)
              │     └─ Configure PHY lanes 0-3 via bank 2
              └─> timer_wait (0xE80A)
                    └─ ~200ms delay for link training
```

### Tunnel Registers

| Register | Address | Purpose |
|---|---|---|
| REG_TUNNEL_CFG_A_LO | 0xB410 | Link config low |
| REG_TUNNEL_CFG_A_HI | 0xB411 | Link config high |
| REG_TUNNEL_CREDITS | 0xB412 | Path credits |
| REG_TUNNEL_CFG_MODE | 0xB413 | Tunnel mode |
| REG_TUNNEL_LINK_STATE | 0xB430 | Bit 0: link up |
| REG_TUNNEL_ADAPTER_MODE | 0xB482 | 0xF0 when enabled |

## Packet Flow

### USB to NVMe (Write Path)

```
USB Host                    ASM2464PD                     NVMe SSD
   │                            │                            │
   │──── CBW (SCSI WRITE) ─────>│                            │
   │     sig=USBC               │                            │
   │     tag=0x1234             │                            │
   │     len=4096               │                            │
   │     cmd=0x2A (WRITE10)     │                            │
   │     LBA=0x100              │                            │
   │                            │                            │
   │──── Data (4096 bytes) ────>│                            │
   │                            │                            │
   │                            │─── NVMe Write CMD ────────>│
   │                            │    opcode=0x02             │
   │                            │    nsid=1                  │
   │                            │    slba=0x100              │
   │                            │    nlb=7 (8 blocks-1)      │
   │                            │                            │
   │                            │<── NVMe Completion ────────│
   │                            │    status=0x00             │
   │                            │                            │
   │<─── CSW (Success) ─────────│                            │
   │     sig=USBS               │                            │
   │     tag=0x1234             │                            │
   │     residue=0              │                            │
   │     status=0x00            │                            │
```

### NVMe to USB (Read Path)

```
USB Host                    ASM2464PD                     NVMe SSD
   │                            │                            │
   │──── CBW (SCSI READ) ──────>│                            │
   │     cmd=0x28 (READ10)      │                            │
   │     LBA=0x100              │                            │
   │                            │                            │
   │                            │─── NVMe Read CMD ─────────>│
   │                            │    opcode=0x01             │
   │                            │                            │
   │                            │<── NVMe Completion ────────│
   │                            │<── Data (via DMA) ─────────│
   │                            │                            │
   │<─── Data (4096 bytes) ─────│                            │
   │<─── CSW (Success) ─────────│                            │
```

## Data Structures

### USB CBW (Command Block Wrapper)

```c
// At 0x8000
struct usb_cbw {
    uint32_t signature;      // 0x43425355 ('USBC')
    uint32_t tag;            // Transaction ID
    uint32_t transfer_len;   // Bytes to transfer
    uint8_t flags;           // Bit 7: direction (1=in)
    uint8_t lun;             // Bits 0-3: LUN
    uint8_t cb_length;       // Command length
    uint8_t command[16];     // SCSI CDB
};
```

### USB CSW (Command Status Wrapper)

```c
// At 0xD800
struct usb_csw {
    uint32_t signature;      // 0x53425355 ('USBS')
    uint32_t tag;            // Echo from CBW
    uint32_t residue;        // Bytes not transferred
    uint8_t status;          // 0=pass, 1=fail, 2=phase error
};
```

### NVMe Submission Queue Entry

```c
// At 0xA000 (DMA: 0x00820000)
struct nvme_sqe {
    uint8_t opcode;          // 0x01=read, 0x02=write
    uint8_t flags;
    uint16_t cid;            // Command ID
    uint32_t nsid;           // Namespace (1)
    uint64_t reserved;
    uint64_t mptr;
    uint64_t prp1, prp2;     // Physical region pages
    uint64_t slba;           // Starting LBA
    uint32_t nlb;            // Block count - 1
    uint32_t control;
};
```

### NVMe Completion Queue Entry

```c
// At 0xB100 (DMA: 0x00800000)
struct nvme_cqe {
    uint32_t result;
    uint32_t reserved;
    uint16_t sq_head;
    uint16_t sq_id;
    uint16_t cid;
    uint16_t status;         // Bit 0: phase, Bits 9-17: status
};
```

## SCSI Command Dispatch

```c
scsi_dispatch_command() {
  switch (G_SCSI_CMD_TYPE) {
    case 0x12: return scsi_inquiry();
    case 0x25: return scsi_read_capacity();
    case 0x28: return nvme_read();   // SCSI READ(10)
    case 0x2A: return nvme_write();  // SCSI WRITE(10)
    case 0x2F: return scsi_verify();
  }
}
```

## DMA Transfer

```c
dma_start_transfer() {
    REG_DMA_MODE = mode;
    REG_DMA_CHAN_AUX = buffer_hi;
    REG_DMA_CHAN_AUX+1 = buffer_lo;
    REG_DMA_XFER_CNT = size;

    // Direction: bit 1 of CTRL2
    // 0 = read (NVMe->USB), 1 = write (USB->NVMe)
    REG_DMA_CHAN_CTRL2 = direction ? 0x02 : 0x00;

    REG_DMA_TRIGGER = 0x01;
    while (REG_DMA_TRIGGER & 0x01);  // Poll done
}
```

## Main Loop

```c
while (1) {
    // 1. Check USB endpoints
    status = REG_USB_EP_STATUS;
    if (status) {
        ep = dispatch_table[status];
        scsi_dispatch_command();
    }

    // 2. Check NVMe completions
    if (nvme_check_cq()) {
        usb_send_csw();
    }

    // 3. Handle PCIe events
    if (REG_INT_PCIE_NVME & 0x20) {
        pcie_handle_link_event();
    }

    // 4. Timer events
    if (REG_INT_SYSTEM & 0x10) {
        system_timer_handler();
    }
}
```

## Key Registers

### USB

| Register | Address | Purpose |
|---|---|---|
| REG_USB_STATUS | 0x9000 | Main status |
| REG_USB_EP_STATUS | 0x9118 | Endpoint bitmap |
| REG_USB_CBW_FLAGS | 0x9127 | CBW flags |
| REG_USB_SPEED | 0x90E0 | USB speed mode |

### PCIe TLP

| Register | Address | Purpose |
|---|---|---|
| REG_PCIE_FMT_TYPE | 0xB210 | TLP type (read/write/cfg) |
| REG_PCIE_ADDR | 0xB218-B21B | 32-bit address |
| REG_PCIE_DATA | 0xB220 | TLP data |
| REG_PCIE_TRIGGER | 0xB254 | Send TLP (write 0x0F) |
| REG_PCIE_STATUS | 0xB296 | Completion status |

### NVMe

| Register | Address | Purpose |
|---|---|---|
| REG_NVME_CTRL | 0xC400 | Controller enable |
| REG_NVME_CMD_OPCODE | 0xC421 | Command opcode |
| REG_NVME_LBA | 0xC422-C424 | LBA address |
| REG_NVME_DOORBELL | 0xC42A | SQ doorbell |

### DMA

| Register | Address | Purpose |
|---|---|---|
| REG_DMA_MODE | 0xC8B0 | Transfer mode |
| REG_DMA_CHAN_AUX | 0xC8B2-3 | Buffer address |
| REG_DMA_XFER_CNT | 0xC8B4-5 | Transfer size |
| REG_DMA_TRIGGER | 0xC8B8 | Start/poll |
| REG_DMA_STATUS | 0xC8D6 | Done/error |

## Implementation Status

```
scsi_transfer_dispatch (0x466B)     [DONE]
  └─> pcie_tunnel_enable (0xC00D)   [DONE]
        ├─> pcie_tunnel_setup (0xCD6C)      [DONE]
        │     └─> pcie_adapter_config (0xC8DB)  [DONE]
        └─> pcie_lane_config (0xD436)       [DONE]
              └─> pcie_lane_config_helper (0xC089)  [DONE]
                    ├─> phy_link_training (0xD702)  [DONE]
                    └─> timer_wait (0xE80A)         [DONE]
```

## Build

```
35,670 / 98,012 bytes (36.3%)
```

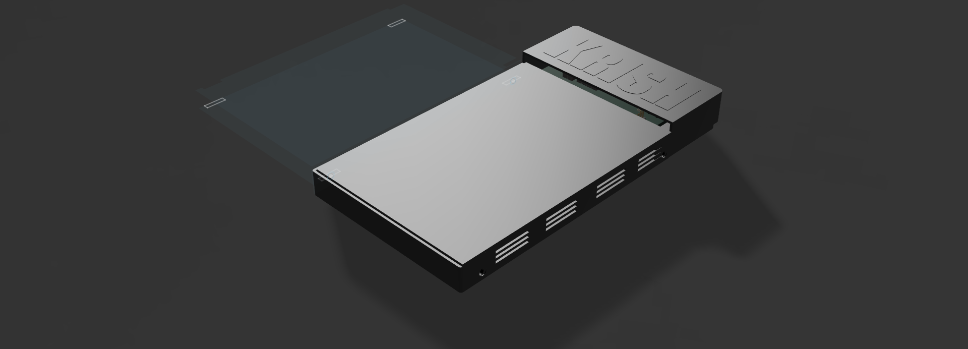
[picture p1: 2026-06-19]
PICTURES/{PCB v49.png

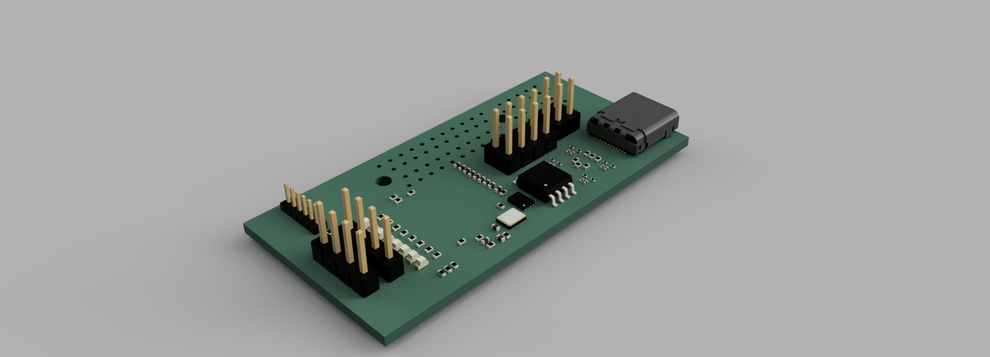
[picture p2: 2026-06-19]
PICTURES/{PCB_v1_2026-Jun-18_11-57-20AM-000_CustomizedView27303303591.png

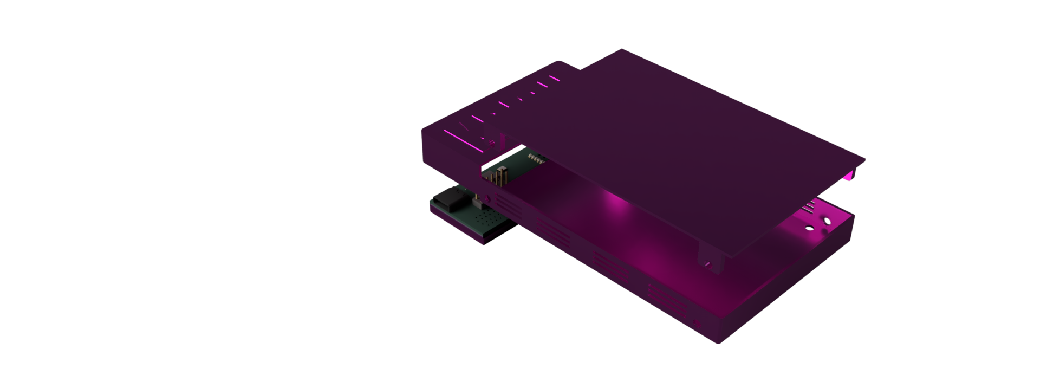
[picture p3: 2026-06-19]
PICTURES/!@45.PNG

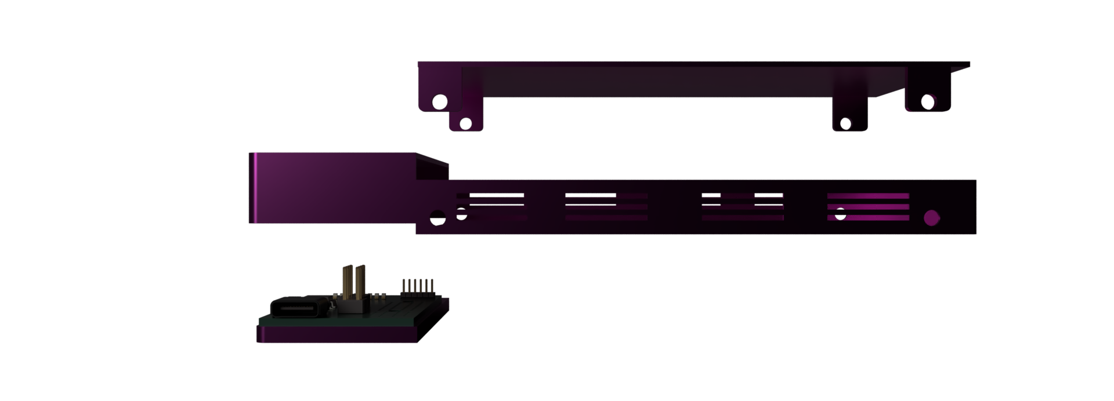
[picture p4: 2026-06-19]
PICTURES/{PCB_v1_2026-Jun-18_05-22-01PM-000_CustomizedView8656417294.png

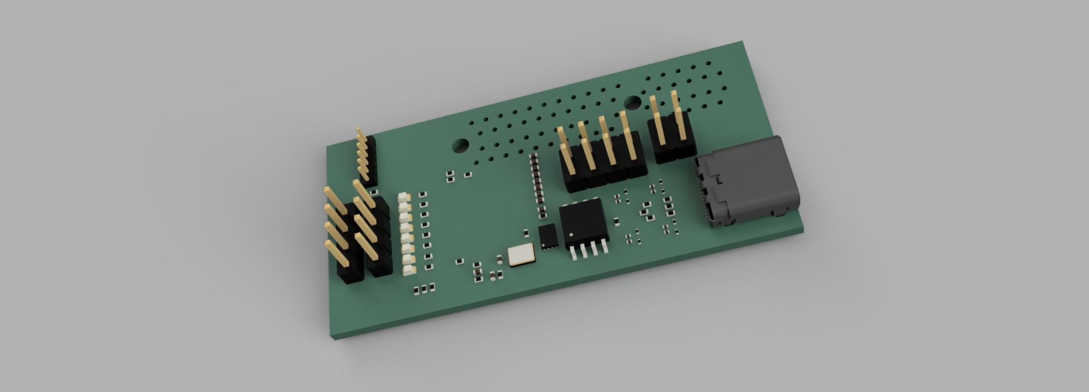
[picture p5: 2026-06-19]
PICTURES/{PCB_v1_2026-Jun-18_11-57-01AM-000_CustomizedView5992248504.png

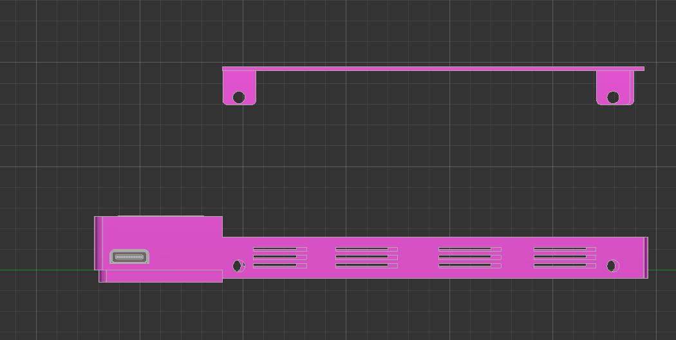
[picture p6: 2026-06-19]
PICTURES/Screenshot 2026-06-19 094433.png

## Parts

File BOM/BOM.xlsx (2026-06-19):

USB4 External Storage Board — Bill of Materials
ASM2464PD USB4 Controller | KiCad Export | DNP = Do Not Populate
# | Reference | Value | Footprint | Qty | Unit (USD) | Total (USD) | DNP | Datasheet / Link
ICs & Active Components
1 | U1 | ASM2464PD USB4 Host Controller | ASM2464PD | 1 | $8.000 | $8.000 |  | https://www.asmedia.com.tw/product/aGaq3YfSP5Yrq0T0/cGaq7XeSw9YRQ5T1
2 | U2 | SPI Flash SOIC-8 (Firmware storage) | SOIC-8_5.3x5.3mm_P1.27mm | 1 | $0.500 | $0.500 |  | http://ww1.microchip.com/downloads/en/DeviceDoc/21832H.pdf
3 | U3 | SPI Flash DFN-8 (Firmware storage) | DFN-8-1EP_3x2mm_P0.5mm | 1 | $0.500 | $0.500 |  | http://ww1.microchip.com/downloads/en/DeviceDoc/21832H.pdf
Crystal
4 | Y1 | 25MHz Crystal SMD 3225-4Pin | Crystal_SMD_3225-4Pin_3.2x2.5mm | 1 | $0.350 | $0.350 |  | —
Connectors
5 | J1 | USB-C Receptacle Amphenol 12401610E4-2A | USB_C_Receptacle_Amphenol | 1 | $1.200 | $1.200 |  | https://www.usb.org/sites/default/files/documents/usb_type-c.zip
6 | J2 | SPI Header 2x04 2.54mm | PinHeader_2x04 | 1 | $0.100 | $0.100 |  | —
7 | J3 | PCIe x4 Connector THT Open | PCIe_x4_tht_open | 1 | $1.500 | $1.500 |  | http://www.ritrontek.com/uploadfile/2016/1026/20161026105231124.pdf
8 | J4 | Chip Annoyers Header 2x02 2.54mm | PinHeader_2x02 | 1 | $0.050 | $0.050 |  | —
9 | J5 | UART Header 1x04 2.54mm | PinHeader_1x04 | 1 | $0.050 | $0.050 |  | —
10 | J6 | I2C Header 1x04 2.54mm | PinHeader_1x04 | 1 | $0.050 | $0.050 |  | —
11 | J7,J8,J9,J10 | 1x06 Header 1.27mm x4 | PinHeader_1x06 | 4 | $0.050 | $0.200 |  | —
Resistors
12 | R1,R2,R20,R26,R29,R39,R41,R42,R43 | 1k ohm 0402 | R_0402_1005Metric | 9 | $0.002 | $0.018 |  | —
13 | R3,R4,R5,R6,R7,R8,R25,R30,R31 | 0 ohm 0402 | R_0402_1005Metric | 9 | $0.002 | $0.018 |  | —
14 | R9,R27,R28,R35,R38 | 4.7k ohm 0402 | R_0402_1005Metric | 5 | $0.002 | $0.010 |  | —
15 | R10,R21,R22 | 10k ohm 0402 | R_0402_1005Metric | 3 | $0.002 | $0.006 |  | —
16 | R11,R12,R13,R14,R15,R16,R17,R18 | 220k ohm 0201 | R_0201_0603Metric | 8 | $0.002 | $0.016 |  | —
17 | R23 | 10k ohm 0402 DNP | R_0402_1005Metric | 1 | $0.002 | $0.002 | DNP | —
18 | R24 | 1k ohm 0402 DNP | R_0402_1005Metric | 1 | $0.002 | $0.002 | DNP | —
19 | R32 | 12.1k ohm 0402 | R_0402_1005Metric | 1 | $0.002 | $0.002 |  | —
20 | R33 | 100k ohm 0402 | R_0402_1005Metric | 1 | $0.002 | $0.002 |  | —
21 | R34,R36,R37 | 4.7k ohm 0402 DNP | R_0402_1005Metric | 3 | $0.002 | $0.006 | DNP | —
Capacitors
22 | C1 | 10pF 0402 | C_0402_1005Metric | 1 | $0.003 | $0.003 |  | —
23 | C2,C3,C4,C5,C6,C7,C8,C9 | 330nF 0201 | C_0201_0603Metric | 8 | $0.003 | $0.024 |  | —
24 | C10,C21 | 1uF 0402 | C_0402_1005Metric | 2 | $0.003 | $0.006 |  | —
25 | C11 | 220pF 0402 DNP | C_0402_1005Metric | 1 | $0.003 | $0.003 | DNP | —
26 | C12,C13,C14,C15,C16,C17,C18,C19 | 220nF 0402 | C_0402_1005Metric | 8 | $0.003 | $0.024 |  | —
27 | C20 | 100nF 0402 | C_0402_1005Metric | 1 | $0.003 | $0.003 |  | —
Diodes & LEDs
28 | D1,D2,D3,D4,D5,D6,D7,D8 | Diode 0201 DNP | D_0201_0603Metric | 8 | $0.010 | $0.080 | DNP | —
29 | D9,D10,D11,D12,D13,D14,D15,D16 | LED 0603 | LED_0603_1608Metric | 8 | $0.020 | $0.160 |  | —
TOTAL — 92 components (29 line items) |  |  |  |  |  | $12.89

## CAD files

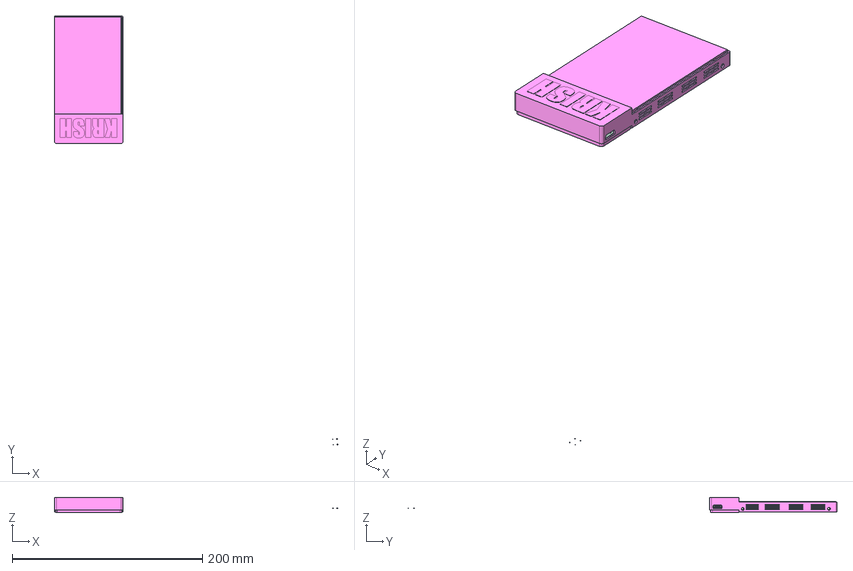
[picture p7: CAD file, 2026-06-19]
CAD/CONTROLLER.step
297.7 x 450.9 x 16.2 mm
R_0402_1005Metric_1 x 29
PinHeader_1x04_P254mm_Vertical x 2
C_0402_1005Metric_1 x 12
C_0201_0603Metric_1 x 8
LED_0603_1608Metric_1 x 8
PinHeader_2x04_P254mm_Vertical
R_0201_0603Metric_1 x 8
DFN-8-1EP_3x2mm_P0.5mm_EP1.3x1.5mm_1
USB_C_Receptacle_Amphenol_12401610E4-2A_1
SOIC-8_5.3x5.3mm_P1.27mm_1
PinHeader_2x02_P254mm_Vertical
PinHeader_1x06_P127mm_Vertical
Crystal_SMD_3225-4Pin_3.2x2.5mm_1
MAIn_PCB

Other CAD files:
CAD/CONTROLLER.3mf
CAD/CONTROLLER.f3d
CAD/CONTROLLER.stl

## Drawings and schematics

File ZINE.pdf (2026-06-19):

# CONTROLLER

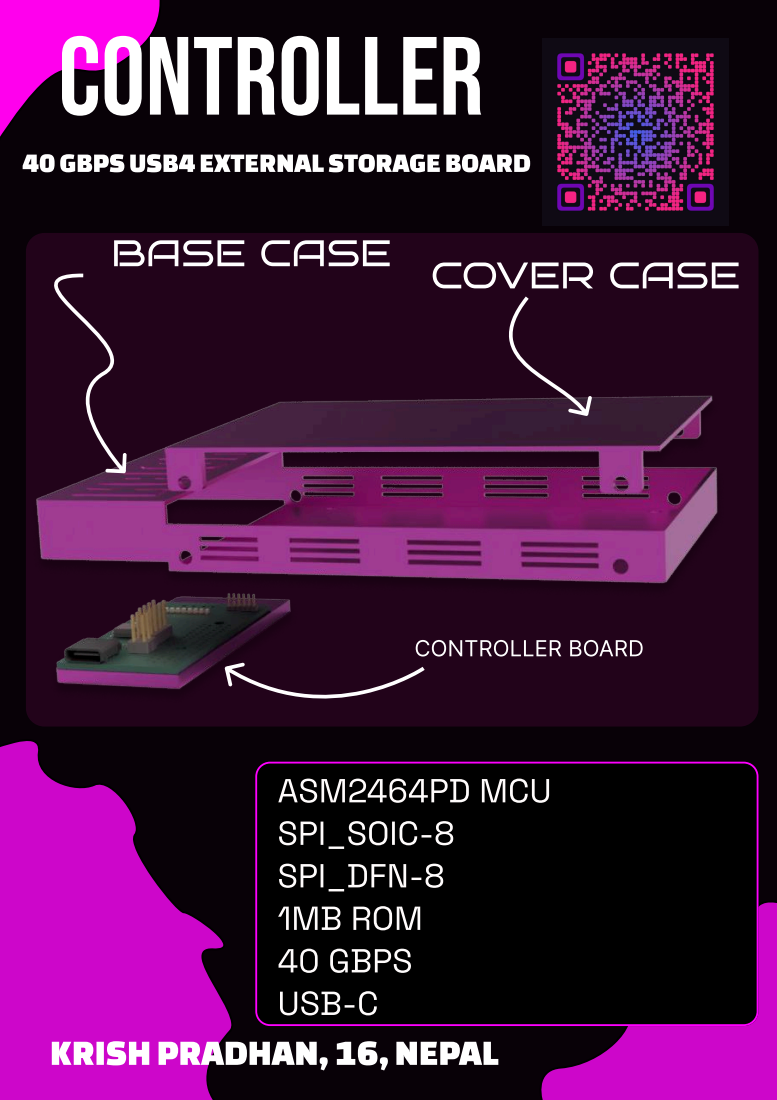
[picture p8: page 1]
BASE CASE; COVER CASE; ASM2464PD MCU SPI_SOIC-8 SPI_DFN-8 1MB ROM 40 GBPS USB-C; CONTROLLER BOARD

40 GBPS USB4 EXTERNAL STORAGE BOARD

KRISH PRADHAN, 16, NEPAL

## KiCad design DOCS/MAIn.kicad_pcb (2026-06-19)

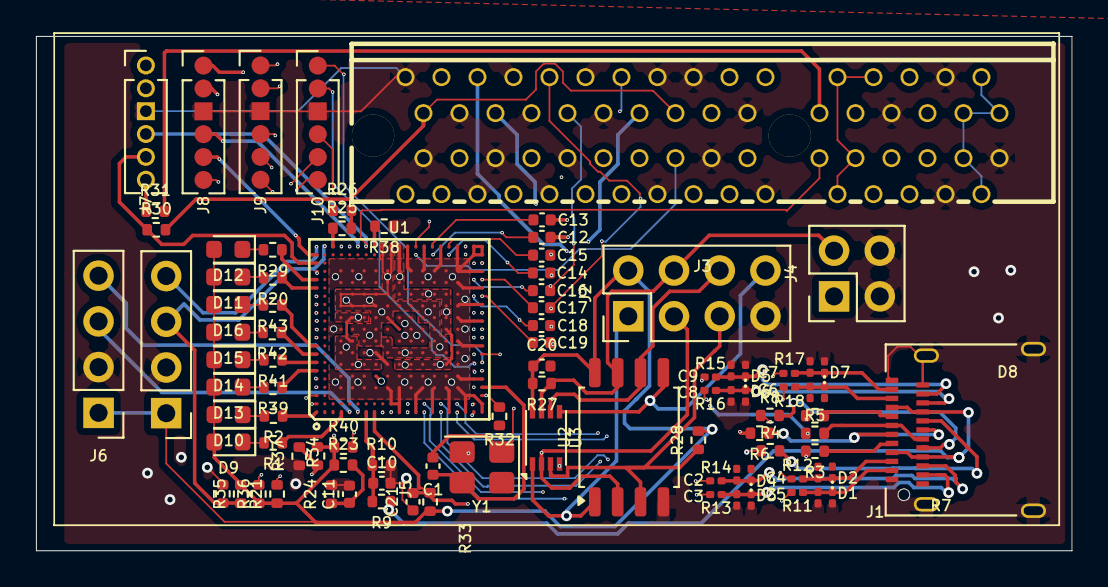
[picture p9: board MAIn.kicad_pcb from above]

Board: 4 copper layers, 57.5 x 28.6 mm, 93 parts (0 on the bottom side), 118 nets.

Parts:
C1: 10p; C_0402_1005Metric
C2, C3, C4, C5, C6, C7, C8, C9: 0.33u; C_0201_0603Metric
C10, C21: 1u; C_0402_1005Metric
C11: 220p; C_0402_1005Metric
C12, C13, C14, C15, C16, C17, C18, C19: 0.22u; C_0402_1005Metric
C20: 0.1u; C_0402_1005Metric
D1, D2, D3, D4, D5, D6, D7, D8: D_0201_0603Metric
D9, D10, D11, D12, D13, D14, D15, D16: LED_0603_1608Metric
J1: USB_C_Receptacle; USB_C_Receptacle_Amphenol_12401610E4-2A
J2: SPIheader; PinHeader_2x04_P2.54mm_Vertical
J3: Bus_PCI_Express_x4; PCIe_x4_tht_open
J4: chip-annoyers; PinHeader_2x02_P2.54mm_Vertical
J5: UART; PinHeader_1x04_P2.54mm_Vertical
J6: I2C; PinHeader_1x04_P2.54mm_Vertical
J7, J8, J9, J10: Conn_01x06; PinHeader_1x06_P1.27mm_Vertical
R1, R2, R20, R24, R26, R29, R39, R41, R42, R43: 1k; R_0402_1005Metric
R3, R4, R5, R6, R7, R8, R25, R30, R31, R40: 0Ω; R_0402_1005Metric
R9, R27, R28, R34, R35, R36, R37, R38: 4.7k; R_0402_1005Metric
R10, R21, R22, R23: 10k; R_0402_1005Metric
R11, R12, R13, R14, R15, R16, R17, R18: 220k; R_0201_0603Metric
R32: 12.1k; R_0402_1005Metric
R33: 100k; R_0402_1005Metric
U1: ASM2464PD
U2: SPI_SOIC-8; SOIC-8_5.3x5.3mm_P1.27mm
U3: SPI_DFN-8; DFN-8-1EP_3x2mm_P0.5mm_EP1.3x1.5mm
Y1: 25MHz; Crystal_SMD_3225-4Pin_3.2x2.5mm

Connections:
+3.3VA: R40.2, U1.H5 (VCCA33)
+3.3V_LDO: C20.1, D9.2 (A), D10.2 (A), D11.2 (A), D12.2 (A), D13.2 (A), D14.2 (A), D15.2 (A), D16.2 (A), J2.2, J5.1, J6.1, R21.1, R22.1, R23.1, R27.2, R28.2, R33.2, R34.2, R35.2, R40.1, U1.D6 (VCCH), U1.D8 (VCCH), U1.D9 (VCCH), U1.D13 (VCCH), U1.E6 (VCCH), U1.E8 (VCCH), U1.E9 (VCCH), U1.E13 (VCCH), U1.F6 (VCCH), U1.F13 (VCCH), U1.H6 (VCCH), U2.8 (VCC), U3.8 (VCC)
+3.3V_SSD: J3.A9 (+3.3V), J3.A10 (+3.3V), J3.B8 (+3.3V), J3.B10 (3.3Vaux)
+5V_VBUS: J1.A4 (VBUS), J1.A9 (VBUS), J1.B4 (VBUS), J1.B9 (VBUS), R9.1
/Main/CC1_C: J1.A5 (CC1), R3.1
/Main/CC2_C: J1.B5 (CC2), R4.1
/Main/PCIe_TX0_C+: C12.2, J3.B14 (PETp0)
/Main/PCIe_TX0_C-: C13.2, J3.B15 (PETn0)
/Main/PCIe_TX1_C+: C14.2, J3.B19 (PETp1)
/Main/PCIe_TX1_C-: C15.2, J3.B20 (PETn1)
/Main/PCIe_TX2_C+: C16.2, J3.B23 (PETp2)
/Main/PCIe_TX2_C-: C17.2, J3.B24 (PETn2)
/Main/PCIe_TX3_C+: C18.2, J3.B27 (PETp3)
/Main/PCIe_TX3_C-: C19.2, J3.B28 (PETn3)
/Main/SBU1_C: J1.A8 (SBU1), R7.1
/Main/SBU2_C: J1.B8 (SBU2), R8.1
/Main/URX0_C+: C3.1, D3.1 (A1), J1.B11 (RX1+), R13.1
/Main/URX0_C-: C2.1, D4.1 (A1), J1.B10 (RX1-), R14.1
/Main/URX1_C+: C7.1, D7.1 (A1), J1.A11 (RX2+), R17.1
/Main/URX1_C-: C6.1, D8.1 (A1), J1.A10 (RX2-), R18.1
/Main/USB2_C_D+: J1.A6 (D+), J1.B6 (D+), R6.1
/Main/USB2_C_D-: J1.A7 (D-), J1.B7 (D-), R5.1
/Main/UTX0_C+: C5.1, D1.1 (A1), J1.A2 (TX1+), R11.1
/Main/UTX0_C-: C4.1, D2.1 (A1), J1.A3 (TX1-), R12.1
/Main/UTX1_C+: C9.1, D5.1 (A1), J1.B2 (TX2+), R15.1
/Main/UTX1_C-: C8.1, D6.1 (A1), J1.B3 (TX2-), R16.1
ActLED1: R1.1, U1.D1 (NVMeACTLED1/GPIO0)
ActLED2: R2.1, U1.A1 (NVMeACTLED2/GPIO3)
ActLED3: R20.1, U1.A16 (NVMeACTLED3/GPIO25)
ActLED4: R29.1, U1.A17 (NVMeACTLED4/GPIO26)
CC1: R3.2, U1.AA6 (CC1)
CC2: R4.2, U1.Y6 (CC2)
CLKREQ0#: J7.5, R21.2, R30.1, U1.A19 (CLKREQ0#/GPIO8)
CLKREQ1#: J8.5, U1.A20 (CLKREQ1#/GPIO14)
CLKREQ2#: J9.5, U1.A14 (CLKREQ2#/GPIO23)
CLKREQ3#: J10.5, U1.A15 (CLKREQ3#/GPIO24)
Card_SMBCLK: J3.B5 (SMCLK), J7.1
Card_SMBDAT: J3.B6 (SMDAT), J7.2
GND: C10.2, C11.2, C20.2, C21.1, D1.2 (A2), D2.2 (A2), D3.2 (A2), D4.2 (A2), D5.2 (A2), D6.2 (A2), D7.2 (A2), D8.2 (A2), J1.A1 (GND), J1.A12 (GND), J1.B1 (GND), J1.B12 (GND), J1.S1 (SHIELD), J2.7, J3.A1 (~PRSNT1), J3.A4 (GND), J3.A12 (GND), J3.A15 (GND), J3.A18 (GND), J3.A20 (GND), J3.A23 (GND), J3.A24 (GND), J3.A27 (GND), J3.A28 (GND), J3.A31 (GND), J3.B4 (GND), J3.B7 (GND), J3.B13 (GND), J3.B16 (GND), J3.B18 (GND), J3.B21 (GND), J3.B22 (GND), J3.B25 (GND), J3.B26 (GND), J3.B29 (GND), J3.B32 (GND), J4.3, J4.4, J5.2, J6.2, J7.3, J8.3, J9.3, J10.3, R10.2, R11.2, R12.2, R13.2, R14.2, R15.2, R16.2, R17.2, R18.2, R24.2, R26.1, R32.2, R36.1, R37.1, R38.1, U1.AA1 (GNDA), U1.AA2 (GNDA), U1.AA5 (GNDA), U1.AA9 (GNDA), U1.AA12 (GNDA), U1.AA14 (GNDA), U1.AA16 (GNDA), U1.AA18 (GNDA), U1.AA20 (GNDA), U1.AA21 (GNDA), U1.D4 (GND), U1.D5 (GND), U1.D11 (GND), U1.D17 (GND), U1.D18 (GND), U1.E4 (GND), U1.E5 (GND), U1.E17 (GND), U1.E18 (GND), U1.F4 (GND), U1.F5 (GND), U1.F8 (GND), U1.F17 (GND), U1.F18 (GND), U1.H4 (GND), U1.H8 (GND), U1.H17 (GND), U1.H18 (GND), U1.J4 (GND), U1.J5 (GND), U1.J6 (GND), U1.J11 (GND), U1.K2 (GND), U1.L1 (GNDA), U1.L2 (GNDA), U1.L4 (GNDA), U1.L5 (GNDA), U1.L9 (GND), U1.L13 (GND), U1.M20 (GNDA), U1.M21 (GNDA), U1.N1 (GNDA), U1.N2 (GNDA), U1.N4 (GNDA), U1.N5 (GNDA), U1.N9 (GND), U1.N11 (GND), U1.N13 (GND), U1.N17 (GNDA), U1.N18 (GNDA), U1.P4 (GNDA), U1.P5 (GNDA), U1.P9 (GND), U1.P11 (GND), U1.P17 (GNDA), U1.P18 (GNDA), U1.P20 (GNDA), U1.P21 (GNDA), U1.R1 (GNDA), U1.R2 (GNDA), U1.T4 (GNDA), U1.T5 (GNDA), U1.T17 (GNDA), U1.T18 (GNDA), U1.T20 (GNDA), U1.T21 (GNDA), U1.U1 (GNDA), U1.U2 (GNDA), U1.U4 (GNDA), U1.U5 (GNDA), U1.U17 (GNDA), U1.U18 (GNDA), U1.V4 (GNDA), U1.V5 (GNDA), U1.V6 (GNDA), U1.V8 (GNDA), U1.V9 (GNDA), U1.V11 (GNDA), U1.V13 (GNDA), U1.V14 (GNDA), U1.V16 (GNDA), U1.V17 (GNDA), U1.V18 (GNDA), U1.V20 (GNDA), U1.V21 (GNDA), U1.W1 (GNDA), U1.W2 (GNDA), U1.Y3 (GNDA), U1.Y5 (GNDA), U1.Y9 (GNDA), U1.Y12 (GNDA), U1.Y14 (GNDA), U1.Y16 (GNDA), U1.Y18 (GNDA), U1.Y20 (GNDA), U1.Y21 (GNDA), U2.4 (GND), U3.4 (GND), Y1.2, Y1.4
GPIO19: J8.6, U1.A10 (PRSNT1#/GPIO19)
GPIO21: J9.6, U1.A12 (PRSNT2#/GPIO21)
GPIO27: J10.6, U1.A18 (PRSNT3#/GPIO27)
HDDPC: R25.1, U1.C21 (HDDPC)
HDD_PC_EN: R25.2, R26.2
I2C_CLK: J6.3, U1.E1 (I2C_CLK_P)
I2C_DATA: J6.4, U1.F1 (I2C_DATA_P)
unnamed: D9.1 (K), R1.2
unnamed: D10.1 (K), R2.2
unnamed: D11.1 (K), R20.2
unnamed: D12.1 (K), R29.2
unnamed: D13.1 (K), R39.2
unnamed: D14.1 (K), R41.2
unnamed: D15.1 (K), R42.2
unnamed: D16.1 (K), R43.2
unnamed: J3.A2 (+12V), J3.A3 (+12V), J3.B1 (+12V), J3.B2 (+12V), J3.B3 (+12V)
unnamed: J3.B17 (~PRSNT2), J3.B31 (~PRSNT2), R30.2
unnamed: J3.B11 (~WAKE), R31.2
P1_LED: R39.1, U1.A6 (P1_LED/GPIO15)
P2_LED: R41.1, U1.A7 (P2_LED/GPIO16)
P3_LED: R42.1, U1.A8 (P3_LED/GPIO17)
P4_LED: R43.1, U1.A9 (P4_LED/GPIO18)
PCIe_RX0+: J3.A16 (PERp0), U1.N21 (PRXP0)
PCIe_RX0-: J3.A17 (PERn0), U1.N20 (PRXN0)
PCIe_RX1+: J3.A21 (PERp1), U1.W21 (PRXP1)
PCIe_RX1-: J3.A22 (PERn1), U1.W20 (PRXN1)
PCIe_RX2+: J3.A25 (PERp2), U1.Y19 (PRXP2)
PCIe_RX2-: J3.A26 (PERn2), U1.AA19 (PRXN2)
PCIe_RX3+: J3.A29 (PERp3), U1.AA13 (PRXP3)
PCIe_RX3-: J3.A30 (PERn3), U1.Y13 (PRXN3)
PCIe_TX0+: C12.1, U1.R20 (PTXP0)
PCIe_TX0-: C13.1, U1.R21 (PTXN0)
PCIe_TX1+: C14.1, U1.U20 (PTXP1)
PCIe_TX1-: C15.1, U1.U21 (PTXN1)
PCIe_TX2+: C16.1, U1.Y17 (PTXP2)
PCIe_TX2-: C17.1, U1.AA17 (PTXN2)
PCIe_TX3+: C18.1, U1.Y15 (PTXP3)
PCIe_TX3-: C19.1, U1.AA15 (PTXN3)
PERST0#: C11.1, J3.A11 (~PERST), J7.4, R23.2, R24.1, U1.G21 (PERST0#)
PERST1#: J8.4, U1.F21 (NC/PERST1#)
PERST2#: J9.4, U1.E21 (NC/PERST2#)
PERST3#: J10.4, U1.D21 (NC/PERST3#)
PE_WAKE#: J7.6, R22.2, R31.1, U1.A13 (PE_WAKE#/GPIO22)
REFCLK1+: J8.1, U1.AA11 (NC/REFCLKP1)
REFCLK1-: J8.2, U1.Y11 (NC/REFCLKN1)
REFCLK2+: J9.1, U1.AA10 (NC/REFCLKP2)
REFCLK2-: J9.2, U1.Y10 (NC/REFCLKN2)
REFCLK3+: J10.1, U1.AA7 (NC/REFCLKP3)
REFCLK3-: J10.2, U1.Y7 (NC/REFCLKN3)
REFCLK+: J3.A13 (REFCLK+), U1.AA8 (REFCLKP0)
REFCLK-: J3.A14 (REFCLK-), U1.Y8 (REFCLKN0)
RST#: C21.2, J4.1, R33.1, U1.H1 (RST#)
SBU1: R7.2, U1.K1 (SBU1)
SBU2: R8.2, U1.J1 (SBU2)
SPI_CLK: J2.6, U1.A5 (GPIO6/SPI_CLK), U2.6 (SCK), U3.6 (SCK)
SPI_CS#: J2.1, U1.A2 (GPIO4/SPI_CS#), U2.1 (~CS), U3.1 (~CS)
SPI_DI: J2.3, U1.A4 (GPIO7/SPI_DI), U2.2 (MISO), U3.2 (MISO)
SPI_DO: J2.8, R34.1, R37.2, U1.A3 (GPIO5/SPI_DO), U2.5 (MOSI), U3.5 (MOSI)
SPI_HOLD#: J2.4, J4.2, R27.1, U2.7 (~HOLD), U3.7 (~HOLD)
SPI_WP#: J2.5, R28.1, U2.3 (~WP), U3.3 (~WP)
TEST_EN: R38.2, U1.H21 (TEST_EN)
UART_RX: J5.4, U1.A21 (PRSNT0#/UART_RX)
UART_TX: J5.3, R35.1, R36.2, U1.B21 (MEMREPAIR/UART_TX)
UREXT: R32.1, U1.AA3 (REXT)
URX0+: C3.2, U1.P1 (URXP0)
URX0-: C2.2, U1.P2 (URXN0)
URX1+: C7.2, U1.Y2 (URXP1)
URX1-: C6.2, U1.Y1 (URXN1)
USB2_D+: R6.2, U1.M1 (UDP)
USB2_D-: R5.2, U1.M2 (UDM)
UTX0+: C5.2, U1.T1 (UTXP0)
UTX0-: C4.2, U1.T2 (UTXN0)
UTX1+: C9.2, U1.V2 (UTXP1)
UTX1-: C8.2, U1.V1 (UTXN1)
VBUS: C10.1, R9.2, R10.1, U1.G1 (VBUS)
VCCL: U1.L6 (VCCL), U1.L16 (VCCL), U1.L17 (VCCL), U1.L18 (VCCL), U1.L20 (VCCL), U1.L21 (VCCL), U1.N6 (VCCL), U1.N16 (VCCL), U1.P6 (VCCL), U1.P16 (VCCL), U1.T6 (VCCL), U1.T16 (VCCL), U1.U6 (VCCL), U1.U11 (VCCL), U1.U13 (VCCL), U1.U14 (VCCL), U1.U16 (VCCL)
VDD: U1.D14 (VDD), U1.D16 (VDD), U1.E11 (VDD), U1.E14 (VDD), U1.E16 (VDD), U1.F9 (VDD), U1.F11 (VDD), U1.F14 (VDD), U1.F16 (VDD), U1.H9 (VDD), U1.H11 (VDD), U1.H13 (VDD), U1.H14 (VDD), U1.H16 (VDD), U1.J8 (VDD), U1.J9 (VDD), U1.J13 (VDD), U1.J14 (VDD), U1.J16 (VDD), U1.J17 (VDD), U1.J18 (VDD), U1.J20 (VDD), U1.J21 (VDD), U1.K20 (VDD), U1.K21 (VDD), U1.L8 (VDD), U1.L11 (VDD), U1.L14 (VDD), U1.N8 (VDD), U1.N14 (VDD), U1.P8 (VDD), U1.P13 (VDD), U1.P14 (VDD), U1.T8 (VDD), U1.T9 (VDD), U1.T11 (VDD), U1.T13 (VDD), U1.T14 (VDD), U1.U8 (VDD), U1.U9 (VDD)
XI: C1.2, U1.AA4 (XI), Y1.3
XO: C1.1, U1.Y4 (XO), Y1.1

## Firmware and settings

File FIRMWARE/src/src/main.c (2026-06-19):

/*
 * ASM2464PD Firmware - Main Entry Point
 *
 * This is the main entry point for the ASM2464PD USB4/Thunderbolt NVMe controller.
 * The firmware is designed for the 8051-compatible CPU core running at ~114MHz.
 *
 * Each function corresponds to a function in the original firmware with its
 * address range documented in the comment header.
 */

#include "types.h"
#include "sfr.h"
#include "registers.h"
#include "globals.h"
#include "app/dispatch.h"
#include "app/scsi.h"
#include "drivers/timer.h"
#include "drivers/phy.h"
#include "drivers/flash.h"
#include "drivers/usb.h"
#include "drivers/pcie.h"
#include "drivers/nvme.h"
#include "drivers/uart.h"
#include "utils.h"
#include "drivers/power.h"
#include "drivers/pd.h"
#include "drivers/usb_descriptors.h"

/* Forward declarations for app layer functions not in headers yet */
extern void event_state_handler(void);         /* app/event_handler.c */
extern void error_state_config(void);          /* app/event_handler.c */
extern void protocol_nop_handler(void);        /* app/protocol.c */

/*===========================================================================
 * Forward declarations
 *===========================================================================*/

/* Main loop */
void main_loop(void);

/* Initialization */
void process_init_table(void);

/* Local functions */
void reg_set_bit_0(uint16_t reg_addr);
void reg_set_bit_0_cpu_exec(void);
void reserved_stub_handler(void);
void main_polling_handler(void);

/*===========================================================================
 * Boot State Verification - startup_0016
 *===========================================================================*/

/*
 * Helper: Load both signature sets for comparison
 * Address: 0x1b7e-0x1b87 (10 bytes)
 *
 * Loads IDATA[0x09-0x0c] into one set and IDATA[0x6b-0x6e] into another
 * for 32-bit comparison.
 */
static void load_both_signatures(uint32_t *sig1, uint32_t *sig2)
{
    /* Load IDATA[0x09-0x0c] (boot signature) */
    *sig1 = I_BOOT_SIG_0 | ((uint32_t)I_BOOT_SIG_1 << 8) |
            ((uint32_t)I_BOOT_SIG_2 << 16) | ((uint32_t)I_BOOT_SIG_3 << 24);
    /* Load IDATA[0x6b-0x6e] (transfer/backup signature) */
    *sig2 = I_TRANSFER_6B | ((uint32_t)I_TRANSFER_6C << 8) |
            ((uint32_t)I_TRANSFER_6D << 16) | ((uint32_t)I_TRANSFER_6E << 24);
}

/*
 * Helper: Compare two 32-bit signatures
 * Note: These are C wrappers for comparison logic.
 * The actual firmware function at 0x0d22 is cmp32() in utils.c.
 *
 * Compares (r0:r1:r2:r3) - (r4:r5:r6:r7) with initial borrow.
 * Returns carry if comparison indicates condition met.
 *
 * Original: setb c means compare >= (sig2 >= sig1)
 *           clr c means compare > (sig2 > sig1)
 */
static uint8_t compare_signatures_ge(uint32_t sig1, uint32_t sig2)
{
    /* setb c before call: check sig2 >= sig1 */
    return sig2 >= sig1;
}

static uint8_t compare_signatures_gt(uint32_t sig1, uint32_t sig2)
{
    /* clr c before call: check sig2 > sig1 */
    return sig2 > sig1;
}

/*
 * startup_0016 - Boot state verification and initialization
 * Address: 0x0016-0x0103 (238 bytes)
 *
 * This is a boot state machine that checks IDATA signatures to determine
 * whether this is a warm boot (signatures match) or cold boot (need to
 * reinitialize). It also handles different boot modes based on XDATA[0x0AF3].
 *
 * Boot states written to XDATA[0x0001]:
 *   0: Normal boot, signatures zero
 *   1: Cold boot, secondary signature non-zero
 *   2: Boot mode == 5
 *   3: Signature mismatch (setb c path)
 *   4: Boot mode == 2 or 4
 *   5: Boot mode == 5 (alt path)
 *   6: Signature mismatch (clr c path)
 *   7: Signature mismatch (second compare)
 *
 * Original disassembly start:
 *   0016: clr a
 *   0017: mov dptr, #0x0001
 *   001a: movx @dptr, a        ; clear boot state
 *   001b: mov r0, #0x6b
 *   001d: lcall 0x0d78         ; load IDATA[0x6b-0x6e]
 *   ...
 */
void startup_0016(void)
{
    uint32_t sig_boot, sig_transfer;
    uint8_t boot_mode;
    uint8_t state_6a;

    /* Clear boot state */
    G_IO_CMD_TYPE = 0;

    /* Load transfer signature from IDATA[0x6b-0x6e] */
    sig_transfer = I_TRANSFER_6B | ((uint32_t)I_TRANSFER_6C << 8) |
                   ((uint32_t)I_TRANSFER_6D << 16) | ((uint32_t)I_TRANSFER_6E << 24);

    /* Check if transfer signature is zero */
    if (sig_transfer == 0) {
        /* Load boot signature from IDATA[0x09-0x0c] */
        sig_boot = I_BOOT_SIG_0 | ((uint32_t)I_BOOT_SIG_1 << 8) |
                   ((uint32_t)I_BOOT_SIG_2 << 16) | ((uint32_t)I_BOOT_SIG_3 << 24);

        if (sig_boot == 0) {
            /* Both signatures zero - normal boot */
            goto boot_dispatch;
        }
        /* Boot signature non-zero but transfer zero - set state 1 */
        G_IO_CMD_TYPE = 1;
        goto boot_dispatch;
    }

    /* Transfer signature non-zero - check boot mode */
    boot_mode = G_XFER_STATE_0AF3;

    if (boot_mode == 0x80) {
        /* Boot mode 0x80 - check I_USB_STATE */
        state_6a = I_USB_STATE;

        switch (state_6a) {
        case 1:
        case 3:
        case 8:
            /* Compare signatures */
            goto compare_signatures_mode80;

        case 2:
        case 4:
            /* Set state 4 */
            G_IO_CMD_TYPE = 4;
            goto boot_dispatch;

        case 5:
            /* Set state 2 */
            G_IO_CMD_TYPE = 2;
            goto boot_dispatch;

        default:
            goto boot_dispatch;
        }
    } else {
        /* Boot mode != 0x80 - different handling */
        state_6a = I_USB_STATE;

        switch (state_6a) {
        case 1:
        case 3:
        case 8:
            /* Jump to 0x00FE path - set state 6 if comparison fails */
            goto compare_signatures_alt;

        case 2:
        case 4:
            /* Compare signatures (at 0x00CA) */
            goto compare_signatures_mode_other;

        case 5:
            /* Set state 5 */
            G_IO_CMD_TYPE = 5;
            goto boot_dispatch;

        default:
            goto boot_dispatch;
        }
    }

compare_signatures_mode80:
    /* Compare IDATA[0x6b-0x6e] with IDATA[0x09-0x0c] byte by byte */
    if (I_TRANSFER_6B == I_BOOT_SIG_0 &&
        I_TRANSFER_6C == I_BOOT_SIG_1 &&
        I_TRANSFER_6D == I_BOOT_SIG_2 &&
        I_TRANSFER_6E == I_BOOT_SIG_3) {
        /* Signatures match - normal boot */
        goto boot_dispatch;
    }

    /* Signatures mismatch - load both and compare with borrow */
    load_both_signatures(&sig_boot, &sig_transfer);

    /* First comparison: setb c (check sig_transfer >= sig_boot) */
    if (!compare_signatures_ge(sig_boot, sig_transfer)) {
        /* Condition not met - set state 3 */
        G_IO_CMD_TYPE = 3;
        goto boot_dispatch;
    }

    /* Second comparison: clr c (check sig_transfer > sig_boot) */
    load_both_signatures(&sig_boot, &sig_transfer);
    if (!compare_signatures_gt(sig_boot, sig_transfer)) {
        /* Condition not met - goto state 4 path */
        goto boot_dispatch;
    }

    /* Fall through to state 4 */
    G_IO_CMD_TYPE = 4;
    goto boot_dispatch;

compare_signatures_alt:
    /* At 0x00FE: Set state 6 and dispatch */
    G_IO_CMD_TYPE = 6;
    goto boot_dispatch;

compare_signatures_mode_other:
    /* Compare IDATA[0x6b-0x6e] with IDATA[0x09-0x0c] byte by byte */
    if (I_TRANSFER_6B == I_BOOT_SIG_0 &&
        I_TRANSFER_6C == I_BOOT_SIG_1 &&
        I_TRANSFER_6D == I_BOOT_SIG_2 &&
        I_TRANSFER_6E == I_BOOT_SIG_3) {
        /* Signatures match */
        goto boot_dispatch;
    }

    /* Mismatch - load both and compare */
    load_both_signatures(&sig_boot, &sig_transfer);

    /* First comparison: setb c */
    if (!compare_signatures_ge(sig_boot, sig_transfer)) {
        /* Set state 7 */
        G_IO_CMD_TYPE = 7;
        goto boot_dispatch;
    }

    /* Second comparison: clr c */
    load_both_signatures(&sig_boot, &sig_transfer);
    if (!compare_signatures_gt(sig_boot, sig_transfer)) {
        goto boot_dispatch;
    }

    /* Set state 6 */
    G_IO_CMD_TYPE = 6;
    /* Fall through to dispatch */

boot_dispatch:
    /* At 0x0104: Read boot state and call table dispatch
     * The table dispatch at 0x0DEF uses boot state to index into
     * a jump table for further initialization.
     * For now, this is a stub - the actual dispatch is complex.
     */
    ;
}

/*===========================================================================
 * Initialization Data Table Processor
 *===========================================================================*/

/*
 * write_xdata_reg - Write value to XDATA register
 * Note: Local helper used by process_init_table.
 * The actual firmware function at 0x0be6 is banked_store_byte() in utils.c.
 */
static void write_xdata_reg(uint8_t addr_h, uint8_t addr_l, uint8_t value)
{
    uint16_t addr = ((uint16_t)addr_h << 8) | addr_l;
    XDATA8(addr) = value;
}

/*
 * process_init_table - Process initialization data table
 * Address: 0x43a3-0x43d1 (47 bytes) - core table loop
 *
 * The original firmware processes a compressed initialization table at code
 * address 0x0620 that initializes various XDATA registers. Since we don't
 * have the same table embedded in our firmware, we perform the equivalent
 * initialization directly.
 *
 * Original table at 0x0620 does:
 *   - Write to 0x0AF0 region (1 byte)
 *   - Write to 0x0864 region (18 bytes)
 *   - Write to 0x0876 region (21 bytes - "00000000" string + metadata)
 *
 * Note: The full initialization is handled by hardware emulation/real HW.
 * This stub allows the firmware to proceed to main_loop.
 */
void process_init_table(void)
{
    /* Perform equivalent initialization that the table would do */

    /* Initialize xfer state region (0x0AF0) */
    G_XFER_STATE_0AF3 = 0x00;

    /* Initialize serial number region (0x0864-0x0875) */
    /* Write "0000000000000000" pattern */
    G_SERIAL_NUM_0864 = '0';
    XDATA8(0x0865) = '0';
    XDATA8(0x0866) = '0';
    XDATA8(0x0867) = '0';
    XDATA8(0x0868) = '0';
    XDATA8(0x0869) = '0';
    XDATA8(0x086A) = '0';
    XDATA8(0x086B) = '0';
    XDATA8(0x086C) = '0';
    XDATA8(0x086D) = '0';
    XDATA8(0x086E) = '0';
    XDATA8(0x086F) = '0';
    XDATA8(0x0870) = '0';
    XDATA8(0x0871) = '0';
    XDATA8(0x0872) = '0';
    XDATA8(0x0873) = '0';

    /* Initialize vendor info region (0x0876-0x088A) */
    /* "Asmedia" + padding */
    XDATA8(0x0876) = 'A';
    XDATA8(0x0877) = 's';
    XDATA8(0x0878) = 'm';
    XDATA8(0x0879) = 'e';
    XDATA8(0x087A) = 'd';
    XDATA8(0x087B) = 'i';
    XDATA8(0x087C) = 'a';
    /* Pad rest with zeros */
    XDATA8(0x087D) = 0x00;
    XDATA8(0x087E) = 0x00;
}

/*===========================================================================
 * Main Entry Point
 *===========================================================================*/

/*
 * Main entry point
 * Address: 0x431a-0x43d2 (184 bytes)
 *
 * Called from reset vector at address 0x0000
 *
 * The firmware entry performs:
 * 1. Clear all internal RAM (256 bytes)
 * 2. Initialize stack pointer to 0x72
 * 3. Call cmd_dispatch (0x0300 via 0x030a)
 * 4. Process initialization data table at 0x0648
 * 5. Enter main processing loop at 0x2f80
 *
 * Original disassembly:
 *   431a: mov r0, #0xff
 *   431c: clr a
 *   431d: mov @r0, a
 *   431e: djnz r0, 0x431d
 *   4320: mov SP, #0x72
 *   4323: lcall 0x030a
 *   4326: ljmp 0x4352   ; continue initialization
 */
void main(void)
{
    /* Note: IDATA clear, SP init (0x72), and DPX init (0x00) are done in crt0.s
     * matching the original firmware at 0x436b-0x4377 */

    /* Process initialization data table */
    process_init_table();

    /* Basic system initialization */
    G_SYSTEM_CTRL = 0x33;

    /* Initialize USB endpoint configuration */
    G_EP_CONFIG_BASE = 0x20;
    G_EP_CONFIG_ARRAY = 0x04;
    G_EP_CONFIG_05A8 = 0x02;
    G_EP_CONFIG_05F8 = 0x04;

    /* Initialize system flags */
    G_USB_CMD_CONFIG = 0x01;
    G_SYS_FLAGS_07ED = 0x00;
    G_SYS_FLAGS_07EE = 0x00;
    G_SYS_FLAGS_07EF = 0x00;

    /* Initialize NVMe */
    REG_NVME_LBA_LOW = 0x02;

    /* Enter main processing loop (never returns) */
    main_loop();
}

/*===========================================================================
 * Main Processing Loop
 *===========================================================================*/

/* External functions from firmware - USB endpoint loop */
extern void usb_ep_loop_180d(uint8_t param);  /* 0x180d */
extern void usb_ep_loop_3419(void);           /* 0x3419 */

/* Return-value wrapper: dispatch_0516 returns result in R7 (0 or 1) */
static uint8_t dispatch_0516_ret(void)
{
    dispatch_0516();
    /* The dispatch function stores result in R7; access via inline asm */
    __asm
        mov dpl, r7
    __endasm;
    return 0;  /* DPL is already set by asm */
}

/* Return-value wrapper: dispatch_0430 returns result in R7 */
static uint8_t dispatch_0430_ret(void)
{
    dispatch_0430();
    __asm
        mov dpl, r7
    __endasm;
    return 0;
}

/*
 * Main processing loop
 * Address: 0x2f80-0x3129 (937 bytes)
 *
 * This is the main polling loop that handles:
 * - Timer/system events
 * - USB events
 * - NVMe events
 * - Power management
 *
 * Original start:
 *   2f80: clr a
 *   2f81: mov dptr, #0x0a59
 *   2f84: movx @dptr, a
 *   2f85: mov dptr, #0xcc32
 *   2f88: lcall 0x5418
 *   2f8b: lcall 0x04d0
 *   ...
 */
void main_loop(void)
{
    uint8_t events;
    uint8_t state;
    uint8_t loop_state;
    uint8_t result;
    uint8_t usb_status;

    /* Clear loop state flag at entry */
    G_LOOP_STATE = 0x00;

    // Setup uart. This is done at 0xe597 in the original fw, but doesn't look like it's implemented here yet.
    // This seems to turn off parity and enable the FIFO?
    REG_UART_FCR |= (1 << 1);
    REG_UART_LCR &= ~(1 << 3);
    // XDATA_REG8(0xCA2E) |= (1 << 0); // this is also done in the same function but doesn't seem necessary?

    /* One-time initialization - called once before main loop (0x1F7C-0x1FAD) */
    timer_link_status_handler();     /* 0x527a */
    phy_config_link_params();        /* 0x04c6 */
    reserved_stub_handler();         /* 0x52ef */
    main_polling_handler();          /* 0x04a8 */
    state_init_4ffb();               /* 0x4ffb -> Sets G_EVENT_FLAGS = 0x04, then 0x87 via dispatch_0520 */
    usb_power_init();                /* 0x0327 */

    /* One-time event flags check (0x1F96-0x1FAD) - only runs on first pass */
    events = G_EVENT_FLAGS;
    if (events & EVENT_FLAGS_ANY) {  /* 0x83 mask */
        if (events & (EVENT_FLAG_ACTIVE | EVENT_FLAG_PENDING)) {  /* 0x81 mask */
            event_state_handler();       /* 0x048a */
        }
        pd_debug_print_flp();            /* 0x05e3 -> Bank1:0xB103 */
        error_state_config();            /* 0x0566 */
        phy_register_config();           /* 0x050c */
    }

    /* Clear interrupt priority for EXT0 and EXT1 (0x1FB0-0x1FB2) */
    IP &= ~0x05;    /* Clear bits 0,2: clr 0xB8.0, clr 0xB8.2 */

    /* Enable external interrupts (0x1FB4-0x1FB8) */
    EX0 = 1;        /* setb 0xA8.0 */
    EX1 = 1;        /* setb 0xA8.2 */
    EA = 1;         /* setb 0xA8.7 */

    /* Main loop starts at 0x1FBA - jumps back here, NOT to 0x1F7C */
    while (1) {

        /* ===== Loop body starts at 0x2fbe ===== */

        /* Disable interrupts for critical section (0x2fbe) */
        EA = 0;

        /* Check system state at 0x0AE2 (0x2fc0-0x2fc9) */
        state = G_SYSTEM_STATE_0AE2;
        if (state == 0 || state == 0x10) {
            goto state_ready;  /* Jump to 0x303f */
        }

        /* State machine processing when state != 0 and state != 0x10 (0x2fcb-0x2ffa) */
        loop_state = G_LOOP_STATE;
        if (loop_state != 0) {
            goto check_loop_state;  /* Jump to 0x2ffb */
        }

        /* G_LOOP_STATE == 0: Check G_STATE_0AE8 (0x2fd1-0x2fe6) */
        if (G_STATE_0AE8 != 0) {
            /* Set G_LOOP_STATE = 0x02 and continue (0x2fdf-0x2fe5) */
            G_LOOP_STATE = 0x02;
            goto check_loop_state;
        }

        /* Check G_EVENT_CTRL_09FA == 0x04 (0x2fd7-0x2fdd) */
        if (G_EVENT_CTRL_09FA == 0x04) {
            /* Set G_LOOP_STATE = 0x01 and initialize (0x2fe7-0x2ff8) */
            G_LOOP_STATE = 0x01;
            G_STATE_0B39 = 0x00;
            G_IO_CMD_STATE = 0xFF;  /* XDATA(0x0002) = 0xFF */
            dispatch_04e9();        /* 0x04e9 -> handler_e8e4 */
        } else {
            /* Set G_LOOP_STATE = 0x02 (0x2fdf-0x2fe4) */
            G_LOOP_STATE = 0x02;
        }

check_loop_state:
        /* Check G_LOOP_STATE value (0x2ffb-0x303d) */
        loop_state = G_LOOP_STATE;

        if (loop_state == 0x01) {
            /* State 0x01: dispatch 0x0516 and check result (0x3002-0x301a) */
            result = dispatch_0516_ret();
            if (result != 0) {
                result = dispatch_0430_ret();
                if (result != 0) {
                    G_LOOP_STATE = 0x02;
                    G_STATE_FLAG_06E6 = G_STATE_FLAG_06E6 - 1;  /* dec a at 0x3017 */
                    dispatch_045d();
                }
            }
        } else if (loop_state == 0x02) {
            /* State 0x02: Check USB status registers (0x3023-0x303d) */
            usb_status = REG_POWER_STATUS & 0x40;  /* 0x92C2 bit 6 */
            /* swap a; rrc a; rrc a; anl a, #0x03 -> extract bits 5:4 >> 4 & 0x03 */
            usb_status = (usb_status >> 4) & 0x03;
            if (usb_status != 0) {
                /* Check REG_USB_PHY_CTRL_91C0 bit 1 (0x3031-0x303d) */
                if (REG_USB_PHY_CTRL_91C0 & USB_PHY_91C0_LINK_UP) {
                    dispatch_0322();  /* 0x0322 -> system_state_handler */
                }
            }
        }
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

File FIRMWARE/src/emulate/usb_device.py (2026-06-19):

"""
ASM2464PD USB Device Emulation

Connects raw-gadget USB device to the 8051 firmware emulator.
ALL USB traffic is passed through to the firmware via MMIO registers.

Architecture:
  Host <--USB--> raw-gadget
                    |
                    └── ALL USB traffic --> firmware via MMIO

Control Transfer Flow:
1. Setup packet (8 bytes) written to 0x9E00-0x9E07
2. USB interrupt triggered (EX0 at 0x0E33)
3. Firmware reads setup packet from MMIO registers
4. Firmware processes request (GET_DESCRIPTOR, SET_ADDRESS, etc.)
5. Firmware writes response to USB buffer at 0x8000
6. Response read back and sent to host

Bulk Transfer Flow (E4/E5 vendor commands):
1. CDB written to 0x910D-0x9112
2. USB interrupt triggers vendor handler (0x5333 -> 0x4583 -> 0x35B7)
3. Firmware processes E4 read or E5 write
4. Response at 0x8000

The firmware handles ALL USB endpoints including control endpoint 0.
USB descriptors are provided by firmware, not hardcoded in Python.

Setup:
  sudo modprobe dummy_hcd raw_gadget
  sudo python emulate/usb_device.py
"""

import os
import sys
import struct
import threading
import time
from typing import Optional, Callable, TYPE_CHECKING
from dataclasses import dataclass

from raw_gadget import (
    RawGadget, RawGadgetError, USBRawEventType, USBControlRequest,
    USBSpeed, USB_DIR_IN, USB_DIR_OUT, USB_DT_ENDPOINT,
    check_raw_gadget_available
)

if TYPE_CHECKING:
    from emu import Emulator

# USB request types
USB_TYPE_STANDARD = 0x00
USB_TYPE_CLASS = 0x20
USB_TYPE_VENDOR = 0x40

# Standard requests
USB_REQ_GET_STATUS = 0x00
USB_REQ_CLEAR_FEATURE = 0x01
USB_REQ_SET_FEATURE = 0x03
USB_REQ_SET_ADDRESS = 0x05
USB_REQ_GET_DESCRIPTOR = 0x06
USB_REQ_SET_DESCRIPTOR = 0x07
USB_REQ_GET_CONFIGURATION = 0x08
USB_REQ_SET_CONFIGURATION = 0x09
USB_REQ_GET_INTERFACE = 0x0A
USB_REQ_SET_INTERFACE = 0x0B

# Descriptor types
USB_DT_DEVICE = 0x01
USB_DT_CONFIG = 0x02
USB_DT_STRING = 0x03
USB_DT_INTERFACE = 0x04
USB_DT_ENDPOINT = 0x05
USB_DT_BOS = 0x0F

# VID:PID
ASM2464_VID = 0xADD1
ASM2464_PID = 0x0001


@dataclass
class USBSetupPacket:
    """USB control transfer setup packet."""
    bmRequestType: int
    bRequest: int
    wValue: int
    wIndex: int
    wLength: int

    @classmethod
    def from_bytes(cls, data: bytes) -> 'USBSetupPacket':
        bmRequestType, bRequest, wValue, wIndex, wLength = struct.unpack('<BBHHH', data[:8])
        return cls(bmRequestType, bRequest, wValue, wIndex, wLength)

    def to_bytes(self) -> bytes:
        return struct.pack('<BBHHH', self.bmRequestType, self.bRequest,
                          self.wValue, self.wIndex, self.wLength)


class USBDevicePassthrough:
    """
    USB device emulation connecting raw-gadget to firmware emulator.

    USB control transfers (setup packets) are passed through to firmware via MMIO.
    E4/E5 vendor commands via bulk endpoints also go through firmware.
    """

    # USB setup packet registers (8-byte setup packet at 0x9E00)
    # These are the actual registers the firmware reads for control transfers
    REG_USB_EP0_DATA = 0x9E00      # EP0 data buffer base address
    REG_USB_SETUP_TYPE = 0x9E00   # bmRequestType
    REG_USB_SETUP_REQ = 0x9E01    # bRequest
    REG_USB_SETUP_VALUE_L = 0x9E02  # wValue low
    REG_USB_SETUP_VALUE_H = 0x9E03  # wValue high
    REG_USB_SETUP_INDEX_L = 0x9E04  # wIndex low
    REG_USB_SETUP_INDEX_H = 0x9E05  # wIndex high
    REG_USB_SETUP_LEN_L = 0x9E06    # wLength low
    REG_USB_SETUP_LEN_H = 0x9E07    # wLength high

    # CDB registers - firmware reads CDB from here for SCSI commands
    REG_CDB_START = 0x910D

    # USB status/control registers
    REG_USB_STATUS = 0x9000
    REG_USB_INT_FLAGS = 0x9101
    REG_USB_INT_PENDING = 0xC802
    REG_USB_EP_READY = 0x9096
    REG_USB_EP_STATUS = 0x90E3

    # Target address registers (for vendor commands)
    REG_TARGET_ADDR_HI = 0xCEB2
    REG_TARGET_ADDR_LO = 0xCEB3
    REG_CMD_TYPE = 0xCEB0

    # Response buffer in XDATA
    USB_BUFFER_ADDR = 0x8000

    def __init__(self, emulator: 'Emulator'):
        """
        Initialize passthrough with emulator reference.

        Args:
            emulator: The 8051 emulator running the firmware
        """
        self.emu = emulator
        self.gadget: Optional[RawGadget] = None
        self.running = False
        self.configured = False
        self.address_set = False
        self.usb_address = 0

        # Endpoint handles (assigned by kernel after enable)
        self.ep_data_in = None   # 0x81 - Data IN (bulk)
        self.ep_data_out = None  # 0x02 - Data OUT (bulk)
        self.ep_stat_in = None   # 0x83 - Status IN (bulk)
        self.ep_cmd_out = None   # 0x04 - Command OUT (bulk)

        # Thread for handling bulk transfers
        self._bulk_thread: Optional[threading.Thread] = None
        self._bulk_running = False

        # Lock for serializing access to the emulator
        # Per EMULATE.md: firmware runs in its own thread, polling via MMIO
        # This lock ensures thread-safe access when multiple threads run firmware
        self._emu_lock = threading.Lock()

        # USB speed for emulator (0=Full, 1=High, 2=Super, 3=Super+)
        self._emu_speed = 1  # Default to High Speed

    def start(self, driver: str = "dummy_udc", device: str = "dummy_udc.0",
              speed: USBSpeed = USBSpeed.USB_SPEED_HIGH):
        """Start the USB device passthrough."""
        available, msg = check_raw_gadget_available()
        if not available:
            raise RuntimeError(f"raw-gadget not available: {msg}")

        # Map USBSpeed enum to our internal speed values for emulator
        # Linux kernel: LOW=1, FULL=2, HIGH=3, SUPER=5, SUPER_PLUS=6
        # Our internal: Full=0, High=1, Super=2, Super+=3
        speed_map = {
            USBSpeed.USB_SPEED_LOW: 0,    # Treat low as full speed
            USBSpeed.USB_SPEED_FULL: 0,
            USBSpeed.USB_SPEED_HIGH: 1,
            USBSpeed.USB_SPEED_SUPER: 2,
        }
        # Handle SUPER_PLUS if it exists in the enum
        if hasattr(USBSpeed, 'USB_SPEED_SUPER_PLUS'):
            speed_map[USBSpeed.USB_SPEED_SUPER_PLUS] = 3
        self._emu_speed = speed_map.get(speed, 1)  # Default to High Speed

        self.gadget = RawGadget()
        self.gadget.open()
        self.gadget.init(driver, device, speed)  # driver_name, device_name, speed
        self.gadget.run()

        self.running = True
        print(f"[USB_PASS] Started on {driver}/{device} at {speed.name} (emu_speed={self._emu_speed})")

    def stop(self):
        """Stop the USB device passthrough."""
        self.running = False
        self._bulk_running = False

        if self._bulk_thread and self._bulk_thread.is_alive():
            self._bulk_thread.join(timeout=1.0)

        if self.gadget:
            self.gadget.close()
            self.gadget = None

        print("[USB_PASS] Stopped")
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
